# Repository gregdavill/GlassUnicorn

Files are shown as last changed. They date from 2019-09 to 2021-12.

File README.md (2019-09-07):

# Glass Unicorn

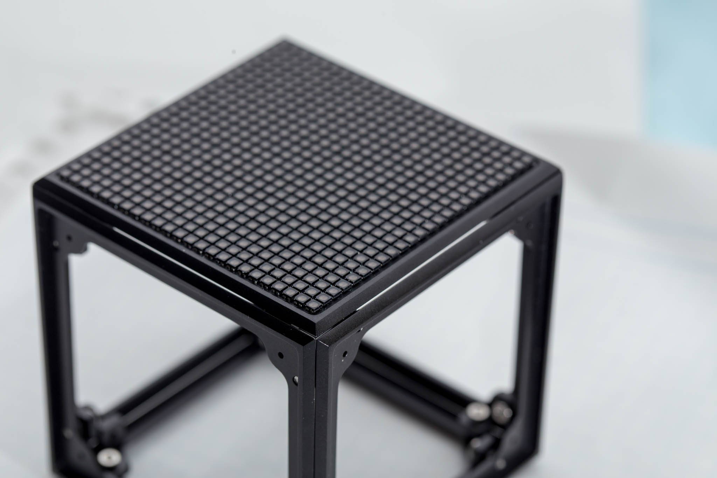
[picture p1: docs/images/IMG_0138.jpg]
LED Cube Top

## Colection of various dense LED matrix projects

	Project status: Work in progress

## Panel_r0.1
 * 24x24 RGB 2020 LEDs
 * Matrix construction with 4bit wide serial input.
 * Optimised for low cost: ~$15 BOM cost

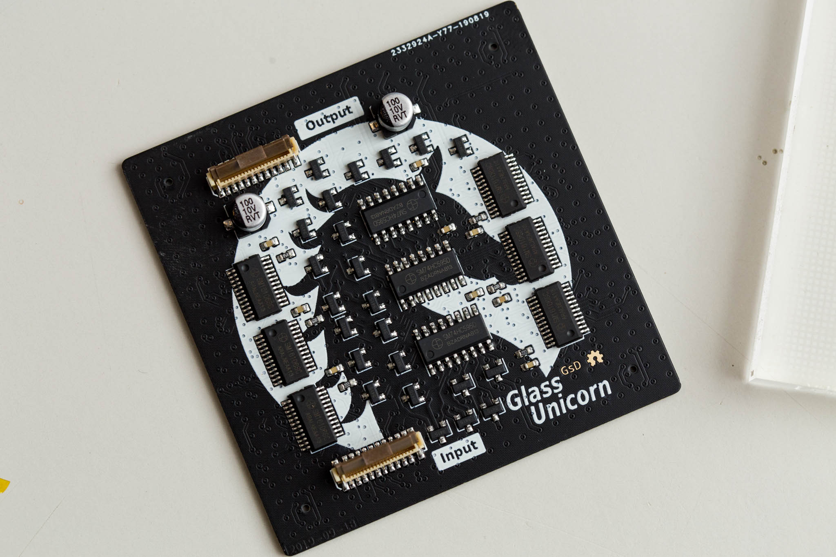
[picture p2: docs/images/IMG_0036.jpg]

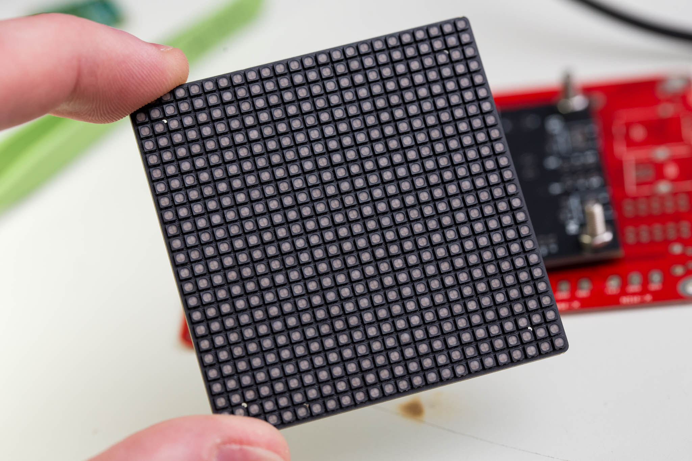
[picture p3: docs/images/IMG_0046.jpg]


## Cube_r0.1
 * Aluminium frame to fit the panels in a cube
 * ~64mm square

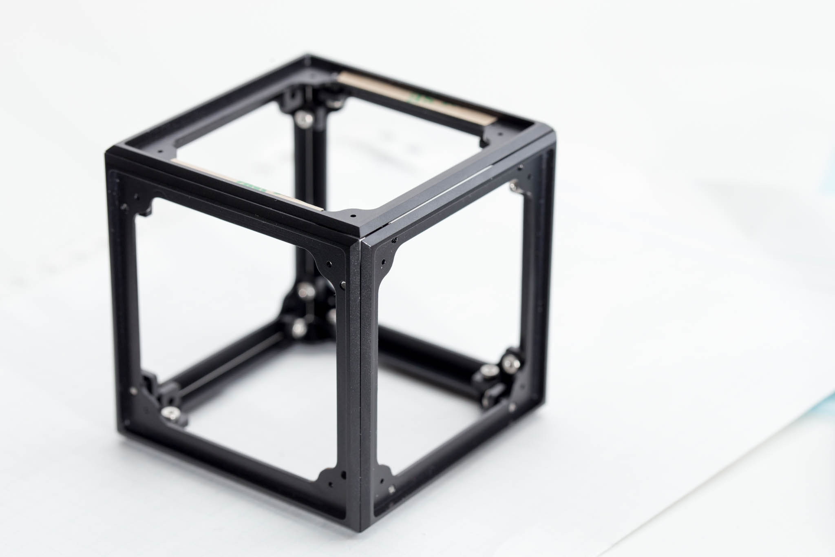
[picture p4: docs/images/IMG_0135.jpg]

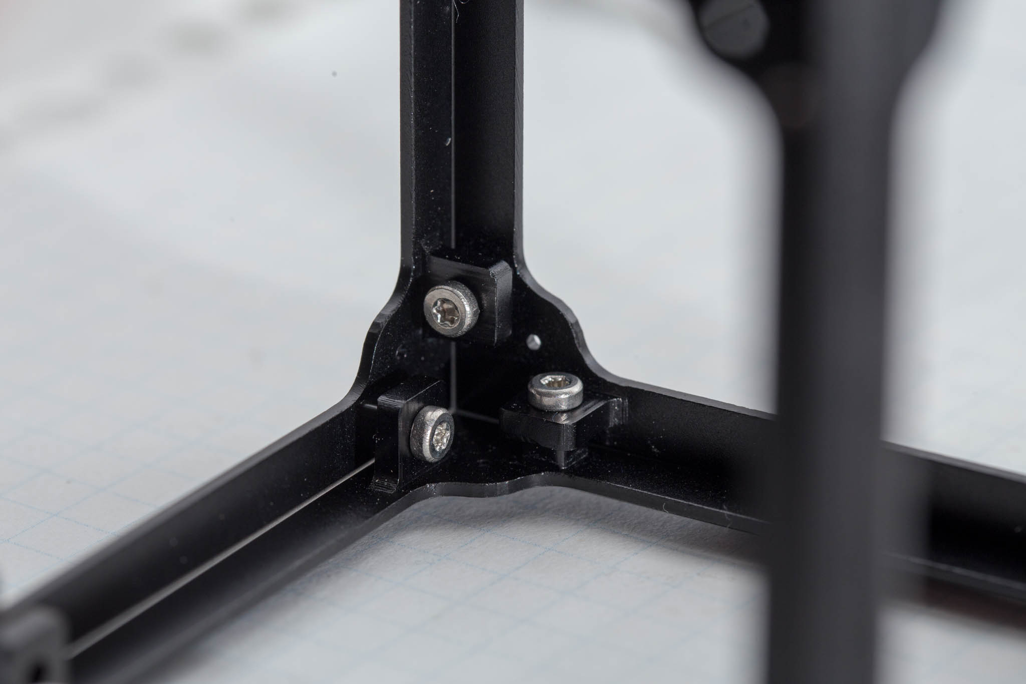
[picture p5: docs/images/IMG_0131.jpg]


## Controller_r0.1

    TBD

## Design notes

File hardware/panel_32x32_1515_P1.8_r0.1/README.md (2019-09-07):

# Panel_32x32_1515_P1.8

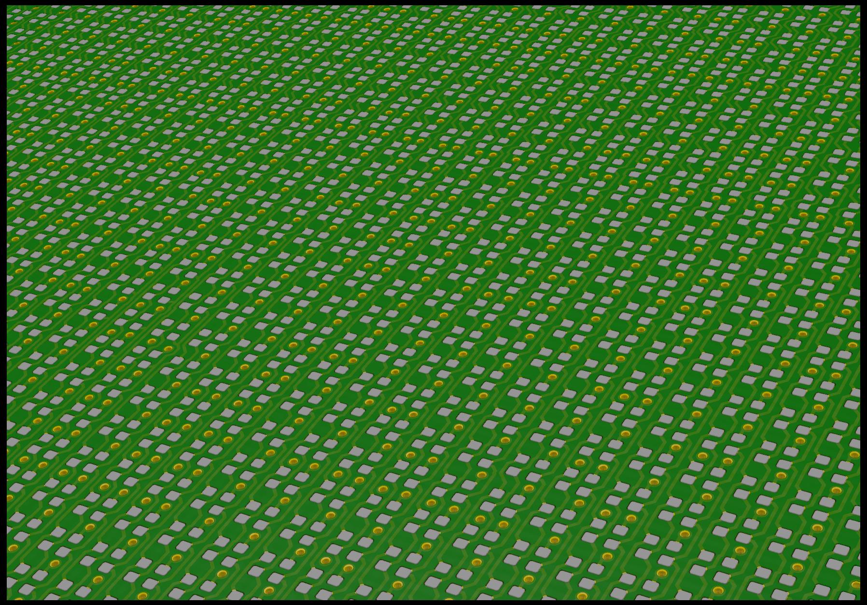
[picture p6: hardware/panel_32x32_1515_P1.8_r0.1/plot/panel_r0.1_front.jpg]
LED Cube Top

## Custom RGB LED panel

	Project status: Boards ordered

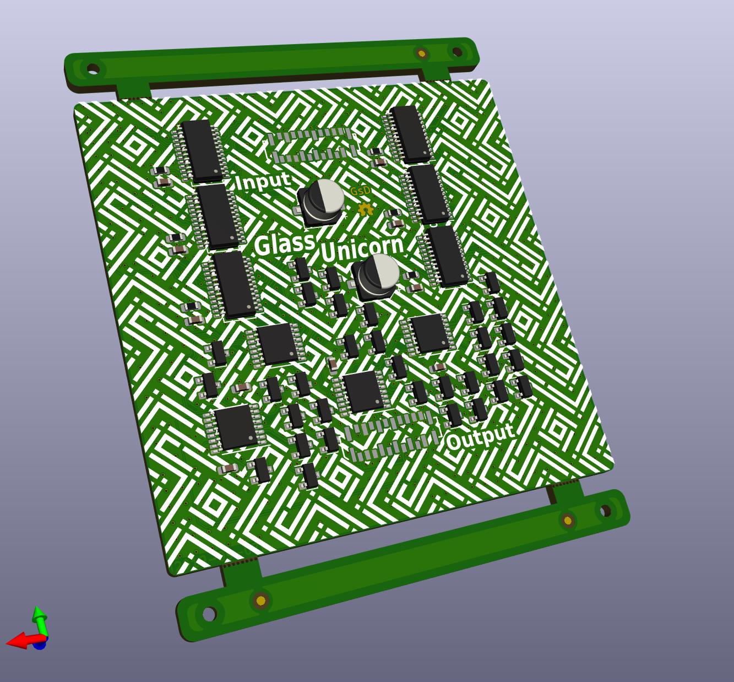
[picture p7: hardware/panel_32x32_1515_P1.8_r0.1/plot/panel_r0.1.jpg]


## Features
 * 32x32 RGB 1515 LEDs
 * Approximatey 1.8mm pixel pitch
 * Matrix construction with 4bit wide serial input.
 * BCM required for colour depth

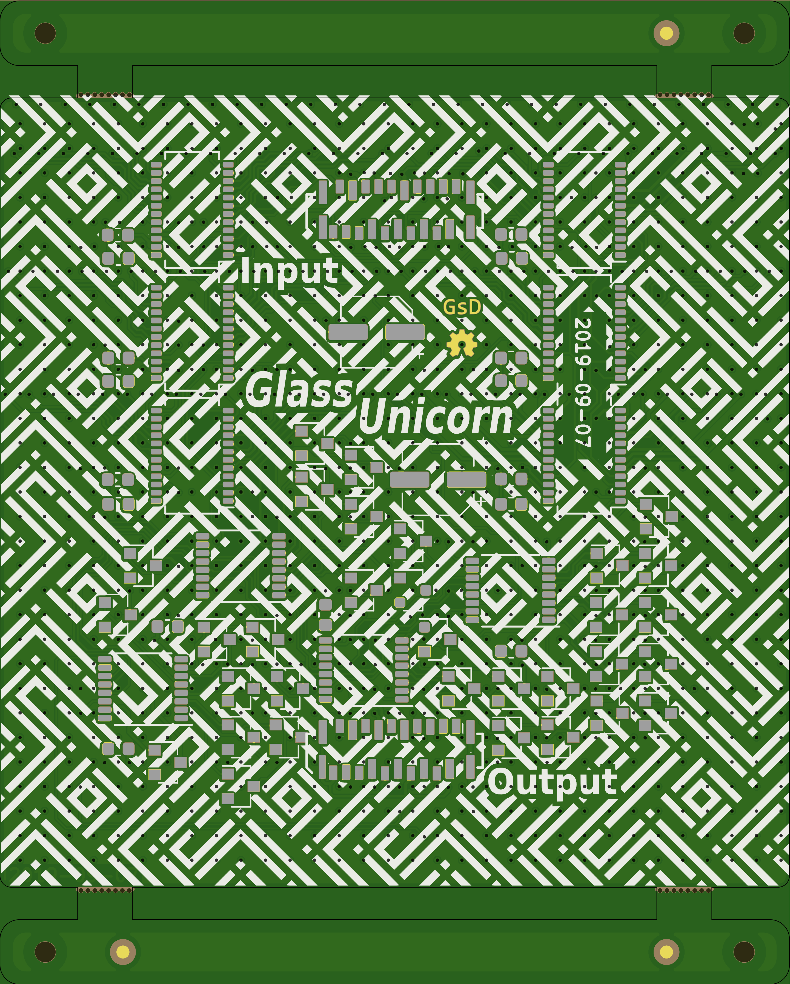
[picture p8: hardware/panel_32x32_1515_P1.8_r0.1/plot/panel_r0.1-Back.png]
"Bottom Photo" Bottom

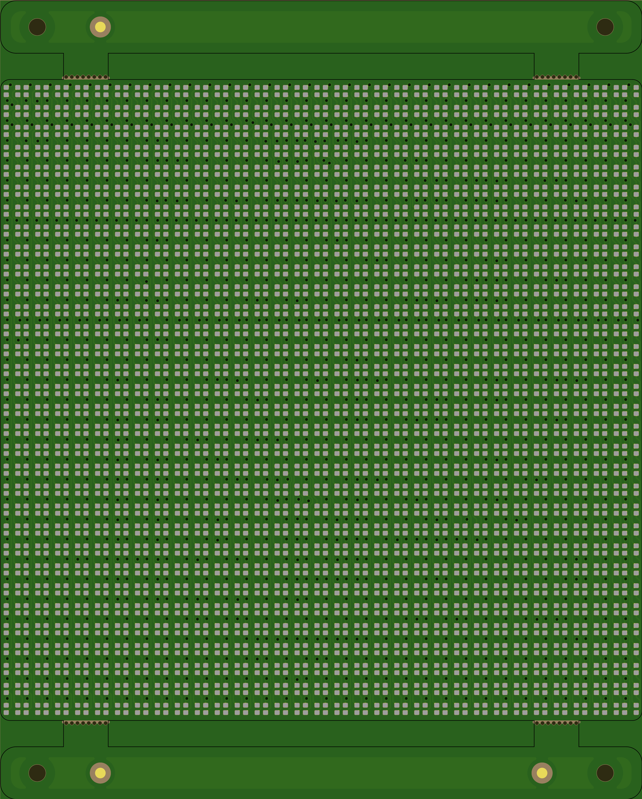
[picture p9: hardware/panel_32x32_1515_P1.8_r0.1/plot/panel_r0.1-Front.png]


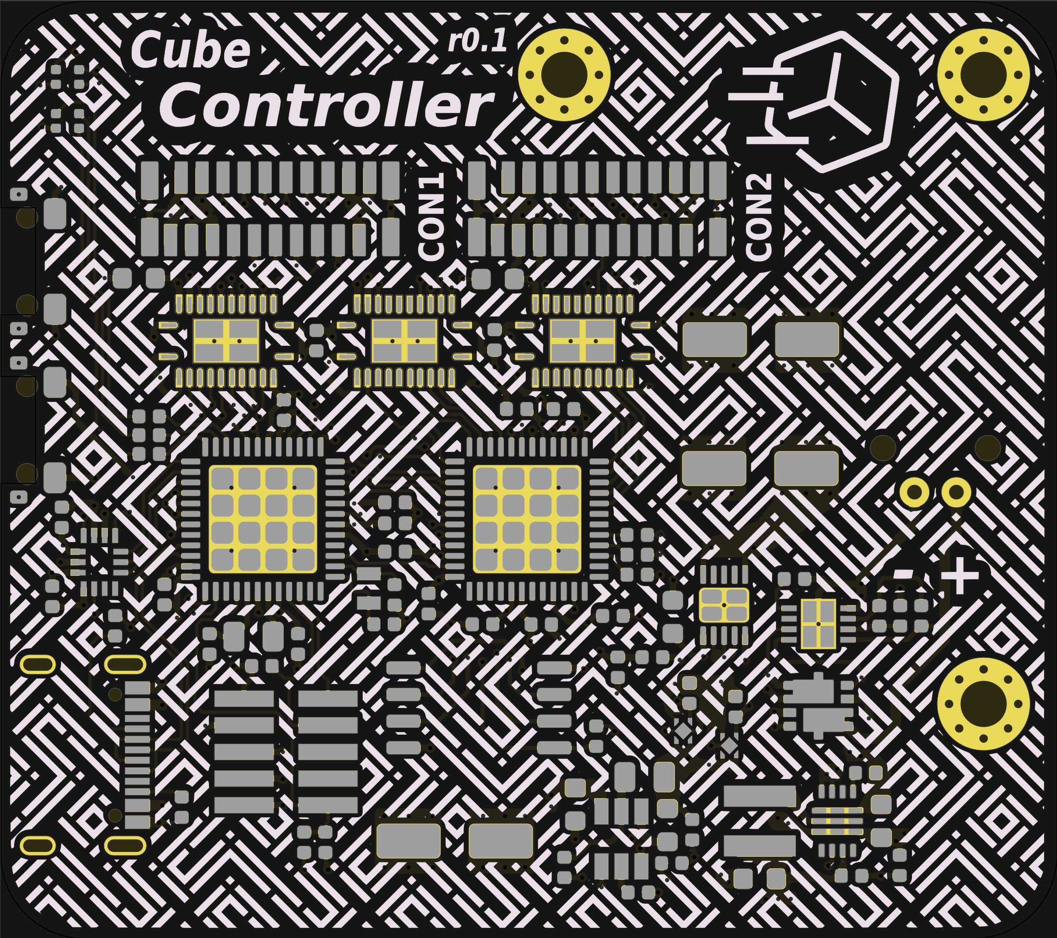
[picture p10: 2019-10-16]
hardware/cube-controller/plot/cube-controller-r0.1-Front.png

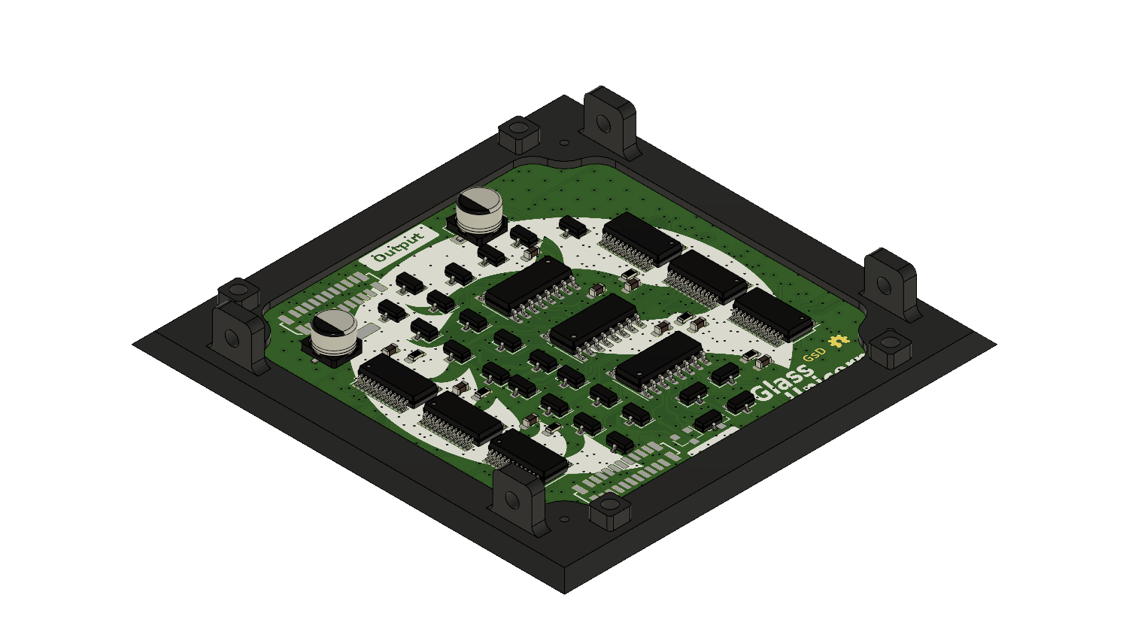
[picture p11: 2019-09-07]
docs/images/GlassUnicorn_Cube_r0.1.png

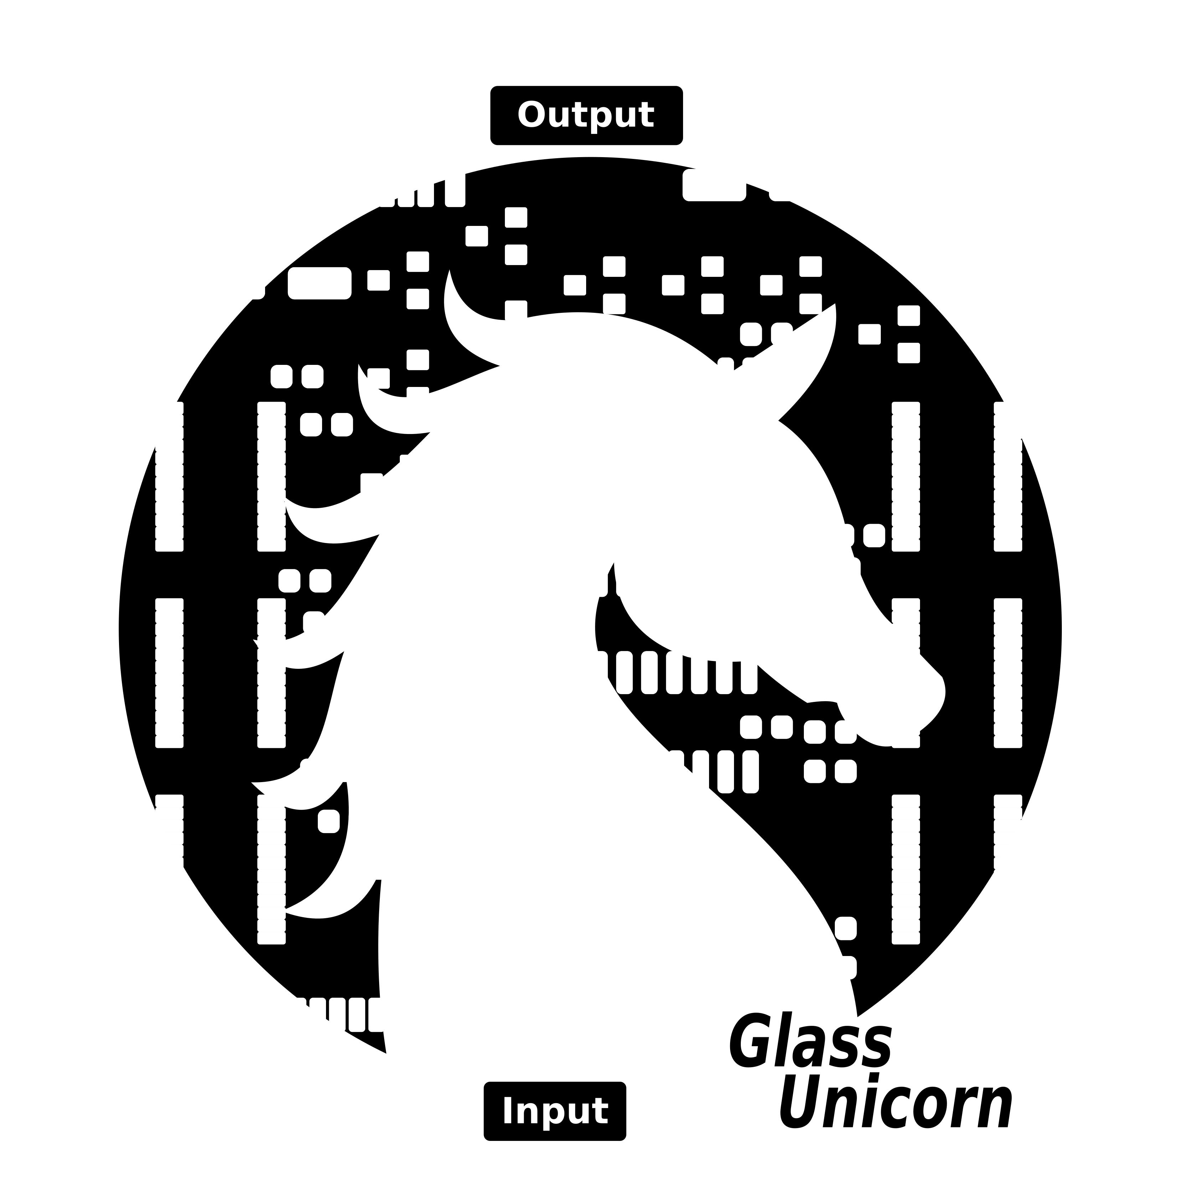
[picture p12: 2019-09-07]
ref/art.png

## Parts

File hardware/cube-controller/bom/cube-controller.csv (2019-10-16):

Source: | /home/greg/projects/GlassUnicorn/hardware/cube-controller/cube-controller.py
Date: | 10/16/2019 11:00 PM
Tool: | SKiDL (0.0.27)
Generator: | /usr/share/kicad/plugins/bom_csv_grouped_by_value.py
Component Count: | 83
Individual Components:
Item | Qty | Reference(s) | Value | LibPart | Footprint | Datasheet | F0 | F1 | F2 | F3 | Manf | PN | datasheet | description | keywords
 |  | C1 | 10uF | C | Capacitor_SMD:C_0603_1608Metric |  | C | C |  |  | Murata Electronics | GRM188R61C106MAALD | ~ | Unpolarized capacitor | cap capacitor
 |  | C2 | 10uF | C | Capacitor_SMD:C_0603_1608Metric |  | C | C |  |  | Murata Electronics | GRM188R61C106MAALD | ~ | Unpolarized capacitor | cap capacitor
 |  | C3 | 100nF | C | Capacitor_SMD:C_0402_1005Metric |  | C | C |  |  | Samsung Electro-Mechanics | CL05B104KP5NNNC | ~ | Unpolarized capacitor | cap capacitor
 |  | C4 | 10uF | C | Capacitor_SMD:C_0603_1608Metric |  | C | C |  |  | Murata Electronics | GRM188R61C106MAALD | ~ | Unpolarized capacitor | cap capacitor
 |  | C5 | 10uF | C | Capacitor_SMD:C_0603_1608Metric |  | C | C |  |  | Murata Electronics | GRM188R61C106MAALD | ~ | Unpolarized capacitor | cap capacitor
 |  | C6 | 1uF | C | Capacitor_SMD:C_0402_1005Metric |  | C | C |  |  | Samsung Electro-Mechanics | CL05A105MQ5NNNC | ~ | Unpolarized capacitor | cap capacitor
 |  | C7 | 1uF | C | Capacitor_SMD:C_0402_1005Metric |  | C | C |  |  | Samsung Electro-Mechanics | CL05A105MQ5NNNC | ~ | Unpolarized capacitor | cap capacitor
 |  | C8 | 1uF | C | Capacitor_SMD:C_0402_1005Metric |  | C | C |  |  | Samsung Electro-Mechanics | CL05A105MQ5NNNC | ~ | Unpolarized capacitor | cap capacitor
 |  | C9 | CP1 | CP1 | Capacitor_SMD:CP_Elec_5x3.9 |  | C | CP1 |  |  | Nichicon | UWX1C101MCL1GB | ~ | Polarized capacitor, US symbol | cap capacitor
 |  | C10 | CP1 | CP1 | Capacitor_SMD:CP_Elec_5x3.9 |  | C | CP1 |  |  | Nichicon | UWX1C101MCL1GB | ~ | Polarized capacitor, US symbol | cap capacitor
 |  | C11 | CP1 | CP1 | Capacitor_SMD:CP_Elec_5x3.9 |  | C | CP1 |  |  | Nichicon | UWX1C101MCL1GB | ~ | Polarized capacitor, US symbol | cap capacitor
 |  | C12 | 100nF | C | Capacitor_SMD:C_0402_1005Metric |  | C | C |  |  | Samsung Electro-Mechanics | CL05B104KP5NNNC | ~ | Unpolarized capacitor | cap capacitor
 |  | C13 | 100nF | C | Capacitor_SMD:C_0402_1005Metric |  | C | C |  |  | Samsung Electro-Mechanics | CL05B104KP5NNNC | ~ | Unpolarized capacitor | cap capacitor
 |  | C14 | 100nF | C | Capacitor_SMD:C_0402_1005Metric |  | C | C |  |  | Samsung Electro-Mechanics | CL05B104KP5NNNC | ~ | Unpolarized capacitor | cap capacitor
 |  | C15 | 100nF | C | Capacitor_SMD:C_0402_1005Metric |  | C | C |  |  | Samsung Electro-Mechanics | CL05B104KP5NNNC | ~ | Unpolarized capacitor | cap capacitor
 |  | C16 | 1uF | C | Capacitor_SMD:C_0402_1005Metric |  | C | C |  |  | Samsung Electro-Mechanics | CL05A105MQ5NNNC | ~ | Unpolarized capacitor | cap capacitor
 |  | C17 | 22pF | C | Capacitor_SMD:C_0402_1005Metric |  | C | C |  |  | Yageo | CC0402JRNPO9BN220 | ~ | Unpolarized capacitor | cap capacitor
 |  | C18 | 22pF | C | Capacitor_SMD:C_0402_1005Metric |  | C | C |  |  | Yageo | CC0402JRNPO9BN220 | ~ | Unpolarized capacitor | cap capacitor
 |  | C19 | 100nF | C | Capacitor_SMD:C_0402_1005Metric |  | C | C |  |  | Samsung Electro-Mechanics | CL05B104KP5NNNC | ~ | Unpolarized capacitor | cap capacitor
 |  | C20 | 100nF | C | Capacitor_SMD:C_0402_1005Metric |  | C | C |  |  | Samsung Electro-Mechanics | CL05B104KP5NNNC | ~ | Unpolarized capacitor | cap capacitor
 |  | C21 | 100nF | C | Capacitor_SMD:C_0402_1005Metric |  | C | C |  |  | Samsung Electro-Mechanics | CL05B104KP5NNNC | ~ | Unpolarized capacitor | cap capacitor
 |  | C22 | 100nF | C | Capacitor_SMD:C_0402_1005Metric |  | C | C |  |  | Samsung Electro-Mechanics | CL05B104KP5NNNC | ~ | Unpolarized capacitor | cap capacitor
 |  | C23 | 100nF | C | Capacitor_SMD:C_0402_1005Metric |  | C | C |  |  | Samsung Electro-Mechanics | CL05B104KP5NNNC | ~ | Unpolarized capacitor | cap capacitor
 |  | C24 | 100nF | C | Capacitor_SMD:C_0402_1005Metric |  | C | C |  |  | Samsung Electro-Mechanics | CL05B104KP5NNNC | ~ | Unpolarized capacitor | cap capacitor
 |  | C25 | 100nF | C | Capacitor_SMD:C_0402_1005Metric |  | C | C |  |  | Samsung Electro-Mechanics | CL05B104KP5NNNC | ~ | Unpolarized capacitor | cap capacitor
 |  | C26 | 10uF | C | Capacitor_SMD:C_0603_1608Metric |  | C | C |  |  | Murata Electronics | GRM188R61C106MAALD | ~ | Unpolarized capacitor | cap capacitor
 |  | C27 | 100nF | C | Capacitor_SMD:C_0402_1005Metric |  | C | C |  |  | Samsung Electro-Mechanics | CL05B104KP5NNNC | ~ | Unpolarized capacitor | cap capacitor
 |  | C28 | 10uF | C | Capacitor_SMD:C_0603_1608Metric |  | C | C |  |  | Murata Electronics | GRM188R61C106MAALD | ~ | Unpolarized capacitor | cap capacitor
 |  | C29 | 100nF | C | Capacitor_SMD:C_0402_1005Metric |  | C | C |  |  | Samsung Electro-Mechanics | CL05B104KP5NNNC | ~ | Unpolarized capacitor | cap capacitor
 |  | C30 | 100nF | C | Capacitor_SMD:C_0402_1005Metric |  | C | C |  |  | Samsung Electro-Mechanics | CL05B104KP5NNNC | ~ | Unpolarized capacitor | cap capacitor
 |  | C31 | 100nF | C | Capacitor_SMD:C_0402_1005Metric |  | C | C |  |  | Samsung Electro-Mechanics | CL05B104KP5NNNC | ~ | Unpolarized capacitor | cap capacitor
 |  | C32 | 100nF | C | Capacitor_SMD:C_0402_1005Metric |  | C | C |  |  | Samsung Electro-Mechanics | CL05B104KP5NNNC | ~ | Unpolarized capacitor | cap capacitor
 |  | C33 | 10uF | C | Capacitor_SMD:C_0603_1608Metric |  | C | C |  |  | Murata Electronics | GRM188R61C106MAALD | ~ | Unpolarized capacitor | cap capacitor
 |  | D1 | LED_ARGB | LED_ARGB | gkl_led:led_rbag_1515 |  | D | LED_ARGB |  |  | Meihua | MHPA1515RGBDT | ~ | RGB LED, anode/red/green/blue | LED RGB diode
 |  | D2 | LED_ARGB | LED_ARGB | gkl_led:led_rbag_1515 |  | D | LED_ARGB |  |  | Meihua | MHPA1515RGBDT | ~ | RGB LED, anode/red/green/blue | LED RGB diode
 |  | FB1 | Ferrite_Bead_Small | Ferrite_Bead_Small | Inductor_SMD:L_0402_1005Metric |  | FB | Ferrite_Bead_Small |  |  | Taiyo Yuden | BK1005HS102-T | ~ | Ferrite bead, small symbol | L ferrite bead inductor filter
 |  | J1 | Conn_01x02 | Conn_01x02 | gkl_conn:SB02B-PASK-2 |  | J | Conn_01x02 |  |  | JST Sales America Inc. | S02B-PASK-2(LF)(SN) | ~ | Generic connector, single row, 01x02, script generated (kicad-library-utils/schlib/autogen/connector/) | connector
 |  | J2 | Conn_01x20_Shielded | Conn_01x20_Shielded | gkl_conn:FH12-20S-0.5SVA(54) |  | J | Conn_01x20_Shielded |  |  | Hirose Electric Co Ltd | FH12-20S-0.5SVA(54) | ~ | Generic shielded connector, single row, 01x20, script generated (kicad-library-utils/schlib/autogen/connector/) | connector
 |  | J3 | Conn_01x20_Shielded | Conn_01x20_Shielded | gkl_conn:FH12-20S-0.5SVA(54) |  | J | Conn_01x20_Shielded |  |  | Hirose Electric Co Ltd | FH12-20S-0.5SVA(54) | ~ | Generic shielded connector, single row, 01x20, script generated (kicad-library-utils/schlib/autogen/connector/) | connector
 |  | J4 | Conn_02x05_Odd_Even | Conn_02x05_Odd_Even | gkl_conn:FTSH-105-XX-X-DV |  | J | Conn_02x05_Odd_Even |  |  | Samtec Inc. | FTSH-105-01-F-DV-K-TR | ~ | Generic connector, double row, 02x05, odd/even pin numbering scheme (row 1 odd numbers, row 2 even numbers), script generated (kicad-library-utils/schlib/autogen/connector/) | connector
 |  | J5 | USB_C_Receptacle_USB2.0 | USB_C_Receptacle_USB2.0 | Connector_USB:USB_C_Receptacle_Palconn_UTC16-G |  | J | USB_C_Receptacle_USB2.0 |  |  | Hirose Electric Co Ltd | CX90M-16P | https://www.usb.org/sites/default/files/documents/usb_type-c.zip | USB 2.0-only Type-C Receptacle connector | usb universal serial bus type-C USB2.0
 |  | L1 | 1uH | L | Inductor_SMD:L_Coilcraft_XxL4020 |  | L | L |  |  | Wurth Electronics Inc. | 78438357010 | ~ | Inductor | inductor choke coil reactor magnetic
 |  | L2 | 2.2uH | L | Inductor_SMD:L_0805_2012Metric |  | L | L |  |  | Murata Electronics | LQM21FN2R2N00D | ~ | Inductor | inductor choke coil reactor magnetic
 |  | L3 | 10uH | L | Inductor_SMD:L_0805_2012Metric |  | L | L |  |  | Murata Electronics | LQM21FN100M70L | ~ | Inductor | inductor choke coil reactor magnetic
 |  | R1 | 510k | R | Resistor_SMD:R_0402_1005Metric |  | R | R |  |  | Yageo | RC0402FR-07510KL | ~ | Resistor | R res resistor
 |  | R2 | 25.3k | R | Resistor_SMD:R_0402_1005Metric |  | R | R |  |  | Yageo | RC0402FR-0725K3L | ~ | Resistor | R res resistor
 |  | R3 | 34.8k | R | Resistor_SMD:R_0402_1005Metric |  | R | R |  |  | Yageo | RC0402FR-0734K8L | ~ | Resistor | R res resistor
 |  | R4 | 750k | R | Resistor_SMD:R_0402_1005Metric |  | R | R |  |  | Yageo | RC0402FR-07750KL | ~ | Resistor | R res resistor
 |  | R5 | 100k | R | Resistor_SMD:R_0402_1005Metric |  | R | R |  |  | Yageo | RC0402FR-07100KL | ~ | Resistor | R res resistor
 |  | R6 | 510k | R | Resistor_SMD:R_0402_1005Metric |  | R | R |  |  | Yageo | RC0402FR-07510KL | ~ | Resistor | R res resistor
 |  | R7 | 93.1k | R | Resistor_SMD:R_0402_1005Metric |  | R | R |  |  | Yageo | RC0402FR-0793K1L | ~ | Resistor | R res resistor
 |  | R8 | 100k | R | Resistor_SMD:R_0402_1005Metric |  | R | R |  |  | Yageo | RC0402FR-07100KL | ~ | Resistor | R res resistor
 |  | R9 | 33.2k | R | Resistor_SMD:R_0402_1005Metric |  | R | R |  |  | Yageo | RC0402FR-0733K2L | ~ | Resistor | R res resistor
 |  | R10 | 10k | R | Resistor_SMD:R_0402_1005Metric |  | R | R |  |  | Yageo | RC0402FR-0710KL | ~ | Resistor | R res resistor
 |  | R11 | 470R | R | Resistor_SMD:R_0402_1005Metric |  | R | R |  |  | Yageo | RC0402FR-07470RL | ~ | Resistor | R res resistor
 |  | R12 | 470R | R | Resistor_SMD:R_0402_1005Metric |  | R | R |  |  | Yageo | RC0402FR-07470RL | ~ | Resistor | R res resistor
 |  | R13 | 470R | R | Resistor_SMD:R_0402_1005Metric |  | R | R |  |  | Yageo | RC0402FR-07470RL | ~ | Resistor | R res resistor
 |  | R14 | 470R | R | Resistor_SMD:R_0402_1005Metric |  | R | R |  |  | Yageo | RC0402FR-07470RL | ~ | Resistor | R res resistor
 |  | R15 | 470R | R | Resistor_SMD:R_0402_1005Metric |  | R | R |  |  | Yageo | RC0402FR-07470RL | ~ | Resistor | R res resistor
 |  | R16 | 470R | R | Resistor_SMD:R_0402_1005Metric |  | R | R |  |  | Yageo | RC0402FR-07470RL | ~ | Resistor | R res resistor
 |  | R17 | 10k | R | Resistor_SMD:R_0402_1005Metric |  | R | R |  |  | Yageo | RC0402FR-0710KL | ~ | Resistor | R res resistor
 |  | R18 | 1k | R | Resistor_SMD:R_0402_1005Metric |  | R | R |  |  | Yageo | RC0402FR-071KL | ~ | Resistor | R res resistor
 |  | R19 | 10k | R | Resistor_SMD:R_0402_1005Metric |  | R | R |  |  | Yageo | RC0402FR-0710KL | ~ | Resistor | R res resistor
 |  | R20 | 10k | R | Resistor_SMD:R_0402_1005Metric |  | R | R |  |  | Yageo | RC0402FR-0710KL | ~ | Resistor | R res resistor
 |  | R21 | 5.1k | 5.1k | Resistor_SMD:R_0402_1005Metric |  | R | R |  |  | Yageo | RC0402FR-075K1L | ~ | Resistor | R res resistor
 |  | R22 | 5.1k | 5.1k | Resistor_SMD:R_0402_1005Metric |  | R | R |  |  | Yageo | RC0402FR-075K1L | ~ | Resistor | R res resistor
 |  | SW1 | SW_Push | SW_Push | gkl_misc:EVQP4 |  | SW | SW_Push |  |  | Panasonic Electronic Components | EVQ-P42B3M | ~ | Push button switch, generic, two pins | switch normally-open pushbutton push-button
 |  | SW2 | SW_Push | SW_Push | gkl_misc:EVQP4 |  | SW | SW_Push |  |  | Panasonic Electronic Components | EVQ-P42B3M | ~ | Push button switch, generic, two pins | switch normally-open pushbutton push-button
 |  | U1 | LTC4367 | LTC4367 | Package_DFN_QFN:DFN-8-1EP_3x3mm_P0.5mm_EP1.66x2.38mm |  | U | LTC4367 |  |  | Linear Technology/Analog Devices | LTC4367IDD#PBF
 |  | U2 | AON7804 | AON7804 | gkl_housings_dfn:DFN3X3_8L_EP2_P |  | U | AON7804 |  |  | Alpha / Omega Semiconductor Inc. | AON7804
 |  | U3 | TPS62135 | TPS62135 | gkl_misc:VQFN-11_3x2mm_P0.5mm |  | U | TPS62135 |  |  | Texas Instruments | TPS621351RGXR
 |  | U4 | TPS561201 | TPS561201 | Package_TO_SOT_SMD:TSOT-23-6 |  | U | TPS561201 |  |  | Texas Instruments | TPS561201DDCT
 |  | U5 | NP115-2.5 | NP115-2.5 | gkl_housings_son:X2SON_4_1.0x1.0mm |  | U | NCP167 |  | http://www.onsemi.com/pub/Collateral/NCP167-D.PDF | ON Semiconductor | NCP115CMX250TCG
 |  | U6 | NP115-1.2 | NP115-1.2 | gkl_housings_son:X2SON_4_1.0x1.0mm |  | U | NCP167 |  | http://www.onsemi.com/pub/Collateral/NCP167-D.PDF | ON Semiconductor | NCP115AMX120TCG
 |  | U7 | ATSAMD51G19A | ATSAMD51G19A | Package_DFN_QFN:QFN-48-1EP_7x7mm_P0.5mm_EP5.15x5.15mm |  | U | ATSAMD51G19A |  |  | Microchip Technology | ATSAMD51G19A-MF
 |  | U8 | ICE40UP5K-SG48ITR | ICE40UP5K-SG48ITR | Package_DFN_QFN:QFN-48-1EP_7x7mm_P0.5mm_EP5.15x5.15mm |  | U | ICE40UP5K-SG48ITR | Package_DFN_QFN:QFN-48-1EP_7x7mm_P0.5mm_EP5.6x5.6mm |  | Lattice Semiconductor Corporation | ICE40UP5K-SG48I | http://www.latticesemi.com/Products/FPGAandCPLD/iCE40Ultra | iCE40 UltraPlus FPGA, 5280 LUTs, 1.2V, 48-pin QFN | FPGA programmable logic
 |  | U9 | SN74AVC8T245PW | SN74AVC8T245PW | Package_DFN_QFN:Texas_RGY_R-PVQFN-N24_EP2.05x3.1mm |  | U | SN74AVC8T245PW | Package_SO:TSSOP-24_4.4x7.8mm_P0.65mm |  | Texas Instruments | SN74AVC8T245RHLR | https://www.ti.com/lit/ds/symlink/sn74avc8t245.pdf | 8-Bit Dual-Supply Bus Transceiver With Configurable Voltage Translation and 3-State Outputs, TSSOP-24 | Noninverting Bidirectional
 |  | U10 | SN74AVC8T245PW | SN74AVC8T245PW | Package_DFN_QFN:Texas_RGY_R-PVQFN-N24_EP2.05x3.1mm |  | U | SN74AVC8T245PW | Package_SO:TSSOP-24_4.4x7.8mm_P0.65mm |  | Texas Instruments | SN74AVC8T245RHLR | https://www.ti.com/lit/ds/symlink/sn74avc8t245.pdf | 8-Bit Dual-Supply Bus Transceiver With Configurable Voltage Translation and 3-State Outputs, TSSOP-24 | Noninverting Bidirectional
 |  | U11 | SN74AVC8T245PW | SN74AVC8T245PW | Package_DFN_QFN:Texas_RGY_R-PVQFN-N24_EP2.05x3.1mm |  | U | SN74AVC8T245PW | Package_SO:TSSOP-24_4.4x7.8mm_P0.65mm |  | Texas Instruments | SN74AVC8T245RHLR | https://www.ti.com/lit/ds/symlink/sn74avc8t245.pdf | 8-Bit Dual-Supply Bus Transceiver With Configurable Voltage Translation and 3-State Outputs, TSSOP-24 | Noninverting Bidirectional
 |  | U12 | BMX160 | BMX160 | Package_LGA:Bosch_LGA-14_3x2.5mm_P0.5mm |  | U | BMX160 |  |  | Bosch Sensortec | BMX160
 |  | U13 | AT25SF081 | AT25SF081 | Package_SO:SOIC-8_5.23x5.23mm_P1.27mm |  | U | AT25SF081 |  |  | Winbond Electronics | W25Q128JVSIM TR
 |  | U14 | LTC4413-2 | LTC4413-2 | Package_DFN_QFN:DFN-10-1EP_3x3mm_P0.5mm_EP1.65x2.38mm |  | U | LTC4413-2 |  |  | Linear Technology/Analog Devices | LTC4413EDD-1#PBF
 |  | Y1 | 32.768kHz | Crystal | Crystal:Crystal_SMD_2012-2Pin_2.0x1.2mm |  | Y | Crystal |  |  | ECS Inc. | ECS-.327-9-12R-C-TR | ~ | Two pin crystal | quartz ceramic resonator oscillator
Collated Components:
Item | Qty | Reference(s) | Value | LibPart | Footprint | Datasheet | F0 | F1 | F2 | F3 | Manf | PN | datasheet | description | keywords
1 | 7 | C1, C2, C4, C5, C26, C28, C33 | 10uF | C | Capacitor_SMD:C_0603_1608Metric | C | C |  |  | Murata Electronics | GRM188R61C106MAALD | ~ | Unpolarized capacitor | cap capacitor
2 | 17 | C3, C12, C13, C14, C15, C19, C20, C21, C22, C23, C24, C25, C27, C29, C30, C31, C32 | 100nF | C | Capacitor_SMD:C_0402_1005Metric | C | C |  |  | Samsung Electro-Mechanics | CL05B104KP5NNNC | ~ | Unpolarized capacitor | cap capacitor
3 | 4 | C6, C7, C8, C16 | 1uF | C | Capacitor_SMD:C_0402_1005Metric | C | C |  |  | Samsung Electro-Mechanics | CL05A105MQ5NNNC | ~ | Unpolarized capacitor | cap capacitor
4 | 3 | C9, C10, C11 | CP1 | CP1 | Capacitor_SMD:CP_Elec_5x3.9 | C | CP1 |  |  | Nichicon | UWX1C101MCL1GB | ~ | Polarized capacitor, US symbol | cap capacitor
5 | 2 | C17, C18 | 22pF | C | Capacitor_SMD:C_0402_1005Metric | C | C |  |  | Yageo | CC0402JRNPO9BN220 | ~ | Unpolarized capacitor | cap capacitor
6 | 2 | D1, D2 | LED_ARGB | LED_ARGB | gkl_led:led_rbag_1515 | D | LED_ARGB |  |  | Meihua | MHPA1515RGBDT | ~ | RGB LED, anode/red/green/blue | LED RGB diode
7 | 1 | FB1 | Ferrite_Bead_Small | Ferrite_Bead_Small | Inductor_SMD:L_0402_1005Metric | FB | Ferrite_Bead_Small |  |  | Taiyo Yuden | BK1005HS102-T | ~ | Ferrite bead, small symbol | L ferrite bead inductor filter
8 | 1 | J1 | Conn_01x02 | Conn_01x02 | gkl_conn:SB02B-PASK-2 | J | Conn_01x02 |  |  | JST Sales America Inc. | S02B-PASK-2(LF)(SN) | ~ | Generic connector, single row, 01x02, script generated (kicad-library-utils/schlib/autogen/connector/) | connector
9 | 2 | J2, J3 | Conn_01x20_Shielded | Conn_01x20_Shielded | gkl_conn:FH12-20S-0.5SVA(54) | J | Conn_01x20_Shielded |  |  | Hirose Electric Co Ltd | FH12-20S-0.5SVA(54) | ~ | Generic shielded connector, single row, 01x20, script generated (kicad-library-utils/schlib/autogen/connector/) | connector
10 | 1 | J4 | Conn_02x05_Odd_Even | Conn_02x05_Odd_Even | gkl_conn:FTSH-105-XX-X-DV | J | Conn_02x05_Odd_Even |  |  | Samtec Inc. | FTSH-105-01-F-DV-K-TR | ~ | Generic connector, double row, 02x05, odd/even pin numbering scheme (row 1 odd numbers, row 2 even numbers), script generated (kicad-library-utils/schlib/autogen/connector/) | connector
11 | 1 | J5 | USB_C_Receptacle_USB2.0 | USB_C_Receptacle_USB2.0 | Connector_USB:USB_C_Receptacle_Palconn_UTC16-G | J | USB_C_Receptacle_USB2.0 |  |  | Hirose Electric Co Ltd | CX90M-16P | https://www.usb.org/sites/default/files/documents/usb_type-c.zip | USB 2.0-only Type-C Receptacle connector | usb universal serial bus type-C USB2.0
12 | 1 | L1 | 1uH | L | Inductor_SMD:L_Coilcraft_XxL4020 | L | L |  |  | Wurth Electronics Inc. | 78438357010 | ~ | Inductor | inductor choke coil reactor magnetic
13 | 1 | L2 | 2.2uH | L | Inductor_SMD:L_0805_2012Metric | L | L |  |  | Murata Electronics | LQM21FN2R2N00D | ~ | Inductor | inductor choke coil reactor magnetic
14 | 1 | L3 | 10uH | L | Inductor_SMD:L_0805_2012Metric | L | L |  |  | Murata Electronics | LQM21FN100M70L | ~ | Inductor | inductor choke coil reactor magnetic
15 | 2 | R1, R6 | 510k | R | Resistor_SMD:R_0402_1005Metric | R | R |  |  | Yageo | RC0402FR-07510KL | ~ | Resistor | R res resistor
16 | 1 | R2 | 25.3k | R | Resistor_SMD:R_0402_1005Metric | R | R |  |  | Yageo | RC0402FR-0725K3L | ~ | Resistor | R res resistor
17 | 1 | R3 | 34.8k | R | Resistor_SMD:R_0402_1005Metric | R | R |  |  | Yageo | RC0402FR-0734K8L | ~ | Resistor | R res resistor
18 | 1 | R4 | 750k | R | Resistor_SMD:R_0402_1005Metric | R | R |  |  | Yageo | RC0402FR-07750KL | ~ | Resistor | R res resistor
19 | 2 | R5, R8 | 100k | R | Resistor_SMD:R_0402_1005Metric | R | R |  |  | Yageo | RC0402FR-07100KL | ~ | Resistor | R res resistor
20 | 1 | R7 | 93.1k | R | Resistor_SMD:R_0402_1005Metric | R | R |  |  | Yageo | RC0402FR-0793K1L | ~ | Resistor | R res resistor
21 | 1 | R9 | 33.2k | R | Resistor_SMD:R_0402_1005Metric | R | R |  |  | Yageo | RC0402FR-0733K2L | ~ | Resistor | R res resistor
22 | 4 | R10, R17, R19, R20 | 10k | R | Resistor_SMD:R_0402_1005Metric | R | R |  |  | Yageo | RC0402FR-0710KL | ~ | Resistor | R res resistor
23 | 6 | R11, R12, R13, R14, R15, R16 | 470R | R | Resistor_SMD:R_0402_1005Metric | R | R |  |  | Yageo | RC0402FR-07470RL | ~ | Resistor | R res resistor
24 | 1 | R18 | 1k | R | Resistor_SMD:R_0402_1005Metric | R | R |  |  | Yageo | RC0402FR-071KL | ~ | Resistor | R res resistor
25 | 2 | R21, R22 | 5.1k | 5.1k | Resistor_SMD:R_0402_1005Metric | R | R |  |  | Yageo | RC0402FR-075K1L | ~ | Resistor | R res resistor
26 | 2 | SW1, SW2 | SW_Push | SW_Push | gkl_misc:EVQP4 | SW | SW_Push |  |  | Panasonic Electronic Components | EVQ-P42B3M | ~ | Push button switch, generic, two pins | switch normally-open pushbutton push-button
27 | 1 | U1 | LTC4367 | LTC4367 | Package_DFN_QFN:DFN-8-1EP_3x3mm_P0.5mm_EP1.66x2.38mm | U | LTC4367 |  |  | Linear Technology/Analog Devices | LTC4367IDD#PBF
28 | 1 | U2 | AON7804 | AON7804 | gkl_housings_dfn:DFN3X3_8L_EP2_P | U | AON7804 |  |  | Alpha / Omega Semiconductor Inc. | AON7804
29 | 1 | U3 | TPS62135 | TPS62135 | gkl_misc:VQFN-11_3x2mm_P0.5mm | U | TPS62135 |  |  | Texas Instruments | TPS621351RGXR
30 | 1 | U4 | TPS561201 | TPS561201 | Package_TO_SOT_SMD:TSOT-23-6 | U | TPS561201 |  |  | Texas Instruments | TPS561201DDCT
31 | 1 | U5 | NP115-2.5 | NP115-2.5 | gkl_housings_son:X2SON_4_1.0x1.0mm | U | NCP167 |  | http://www.onsemi.com/pub/Collateral/NCP167-D.PDF | ON Semiconductor | NCP115CMX250TCG
32 | 1 | U6 | NP115-1.2 | NP115-1.2 | gkl_housings_son:X2SON_4_1.0x1.0mm | U | NCP167 |  | http://www.onsemi.com/pub/Collateral/NCP167-D.PDF | ON Semiconductor | NCP115AMX120TCG
33 | 1 | U7 | ATSAMD51G19A | ATSAMD51G19A | Package_DFN_QFN:QFN-48-1EP_7x7mm_P0.5mm_EP5.15x5.15mm | U | ATSAMD51G19A |  |  | Microchip Technology | ATSAMD51G19A-MF
34 | 1 | U8 | ICE40UP5K-SG48ITR | ICE40UP5K-SG48ITR | Package_DFN_QFN:QFN-48-1EP_7x7mm_P0.5mm_EP5.15x5.15mm | U | ICE40UP5K-SG48ITR | Package_DFN_QFN:QFN-48-1EP_7x7mm_P0.5mm_EP5.6x5.6mm |  | Lattice Semiconductor Corporation | ICE40UP5K-SG48I | http://www.latticesemi.com/Products/FPGAandCPLD/iCE40Ultra | iCE40 UltraPlus FPGA, 5280 LUTs, 1.2V, 48-pin QFN | FPGA programmable logic
35 | 3 | U9, U10, U11 | SN74AVC8T245PW | SN74AVC8T245PW | Package_DFN_QFN:Texas_RGY_R-PVQFN-N24_EP2.05x3.1mm | U | SN74AVC8T245PW | Package_SO:TSSOP-24_4.4x7.8mm_P0.65mm |  | Texas Instruments | SN74AVC8T245RHLR | https://www.ti.com/lit/ds/symlink/sn74avc8t245.pdf | 8-Bit Dual-Supply Bus Transceiver With Configurable Voltage Translation and 3-State Outputs, TSSOP-24 | Noninverting Bidirectional
36 | 1 | U12 | BMX160 | BMX160 | Package_LGA:Bosch_LGA-14_3x2.5mm_P0.5mm | U | BMX160 |  |  | Bosch Sensortec | BMX160
37 | 1 | U13 | AT25SF081 | AT25SF081 | Package_SO:SOIC-8_5.23x5.23mm_P1.27mm | U | AT25SF081 |  |  | Winbond Electronics | W25Q128JVSIM TR
38 | 1 | U14 | LTC4413-2 | LTC4413-2 | Package_DFN_QFN:DFN-10-1EP_3x3mm_P0.5mm_EP1.65x2.38mm | U | LTC4413-2 |  |  | Linear Technology/Analog Devices | LTC4413EDD-1#PBF
39 | 1 | Y1 | 32.768kHz | Crystal | Crystal:Crystal_SMD_2012-2Pin_2.0x1.2mm | Y | Crystal |  |  | ECS Inc. | ECS-.327-9-12R-C-TR | ~ | Two pin crystal | quartz ceramic resonator oscillator

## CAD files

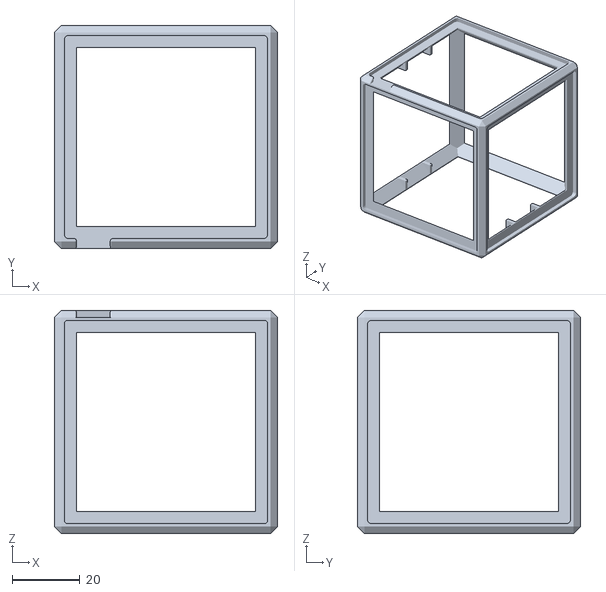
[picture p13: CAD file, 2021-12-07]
hardware/cube_r0.1/GlassUnicorn_Cube_Unibody_r0.2.stl
66.0 x 66.0 x 66.0

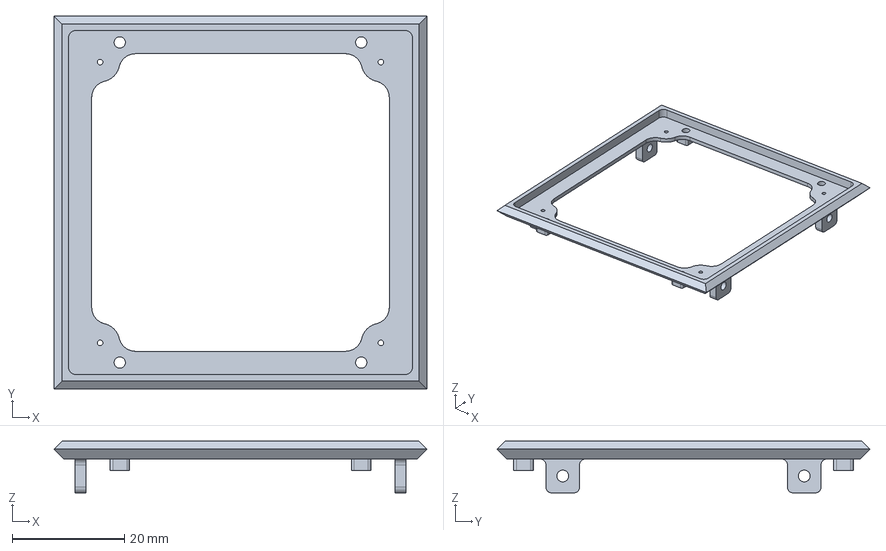
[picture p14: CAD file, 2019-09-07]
hardware/cube_r0.1/GlassUnicorn_Cube_r0.1.iges
66.4 x 66.4 x 9.20 mm

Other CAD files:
hardware/cube_r0.1/GlassUnicorn_Cube_Unibody_r0.2.prt
hardware/cube_r0.1/GlassUnicorn_Cube_r0.1.f3d

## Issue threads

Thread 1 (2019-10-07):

Suggestion: use high-side drivers with discharge to prevent ghosting

electroniceel, 2019-10-07:
You posted on twitter that you had some ghosting issues with your led panel.

One reason for ghosting can be charge that is built up by the high-side drivers and not drained before switching to the next row/column (whatever you use the highside for).

One solution is to use dedicated highside led drivers which have integrated transistors which actively pull low all outputs that are not enabled. For example this one:
https://lcsc.com/product-detail/LED-Drivers_TC7258E_C126213.html
(sorry, no english datasheet, but the Google translation looks fine to me)

I've read from other people that use resistors to add some minimum load on each highside-output. Don't know how well that works, probably more timing-dependant than the active drain.

gregdavill, 2019-10-13:
Interesting! I'll have to pick some up and experiment with them.

Looks like it wont be a drop in replacement. I also want to fully investigate exactly what conditions are causing the ghosting in my case.

arturo182, 2019-10-20:
Would it then also help to bodge pull down resistors on the mosfets on the existing design?

gregdavill, 2019-10-20:
If the issue turns out to be stray capacitance in columns that were activated without any rows active, we can probably try adding code to the gateware that essentially "skips" over any column fitting this description.

Adding hardware bodges will be good for debugging!

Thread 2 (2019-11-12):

Questions about FPGA source code

myxingchao, 2019-11-12:
After reading your project, I am very interested, I don't know how to get the FPGA source code.

greigs, 2019-11-13:
Some might be here.. I'm still waiting on my FPGA to try it.
https://github.com/gregdavill/ice40-playground/tree/master/cores/hub75

myxingchao, 2019-11-13:
Thank you for your reply, I am looking at the file is not found in the schematic of the control panel, I want to understand the principle to modify, maybe I can use ARM to try to develop

greigs, 2019-11-13:
This isn't schematic code. It is the FPGA code.
https://github.com/gregdavill/ice40-playground/tree/GlassUnicorn_24x24/projects/rgb_panel/rtl

gregdavill, 2019-11-28:
The panels are driven by an FPGA on the controller PCB. It's based on the rgb_panel code from here: https://github.com/smunaut/ice40-playground

This in turn is controlling the LEDs using Binary Coded Modulation. Here is a very detailed video on how this modulation scheme works. https://www.youtube.com/watch?v=Sq8SxVDO5wE

You should be able to develop similar code on an ARM if you wish.

gregdavill, 2019-11-28:
Here is another good video explaining how to drive panels similar to mine. Which would be a good starting point if you want to write your own. https://www.youtube.com/watch?v=6iHTbGsnI8Q

Closed 2019-12-01.

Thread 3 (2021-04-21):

P-Channel MOSFET Selection

mister-walter, 2021-04-21:
I'm trying to build one of your LED cubes, and was wondering if you could give any more information on the P-Channel MOSFETs that you used. I don't know a whole lot about component selection so I'm kind of flying by the seat of my pants here - I wasn't able to find any information about a P-Channel MOSFET with a designation 3412 (this is what appears in the BOM).

I'm mainly unsure about what max current capacity I should select for - the datasheet for the 2020 RGB LEDs that you linked on your blog indicates 20mA max forward current (I assume total between all color channels?), so my back-of-the-envelope calculation is 24 LEDs per row * 20mA = 0.5ish A. Therefore I should be looking for something with `Id > 1` and `Pd > 1.125W` (0.5A at 4.5V), right?

Thanks for posting this project!

gregdavill, 2021-04-21:
The parts are from LCSC, but it appears they no longer sell them, and they've removed the listing.

From the invoice I have when I bought them. They have the following description:
`3415, Shenzhen Fuman Elec, P-Channel 12V 4A 1.4V @ 250uA 55mΩ @ 3A,4.5V MOSFET `

mister-walter, 2021-04-22:
Thanks! I was able to find a similar MOSFET on LCSC.

Unrelated question - how did you select the resistor values for the TLC59025 clones? I'm planning to use an MBI5024 and I think I understand how to calculate the required resistor for a desired output current, but how did you determine the output currents for the 3 channels/what output current did you end up selecting for each?

gregdavill, 2021-04-22:
I used the values from an off the shelf 64x64 LED panel. But it hod different controller ICs. So my white balance isn't great.

I think my currents are all around the 2-5mA range. I opted to go a bit lower to get better dynamic range. and I didn't need to blind anyone.

I'd recommend building up a board, and maybe trying to fit a trim-pot for each channel, and then with actual content displayed on the panel adjust for the best looking image, then use those values for the rest of the panels.

Closed 2021-04-28.

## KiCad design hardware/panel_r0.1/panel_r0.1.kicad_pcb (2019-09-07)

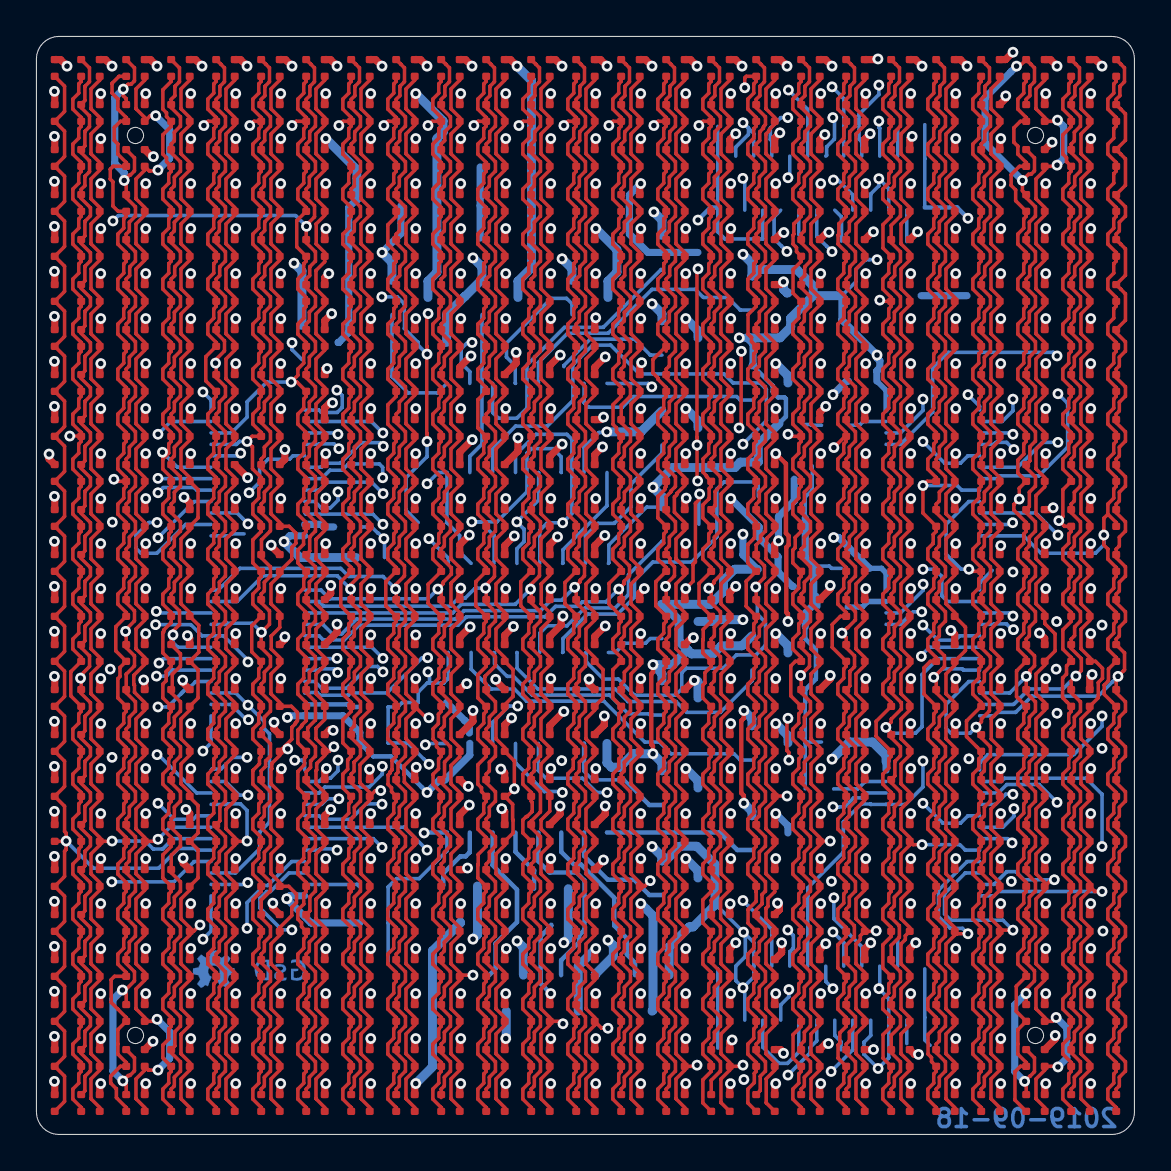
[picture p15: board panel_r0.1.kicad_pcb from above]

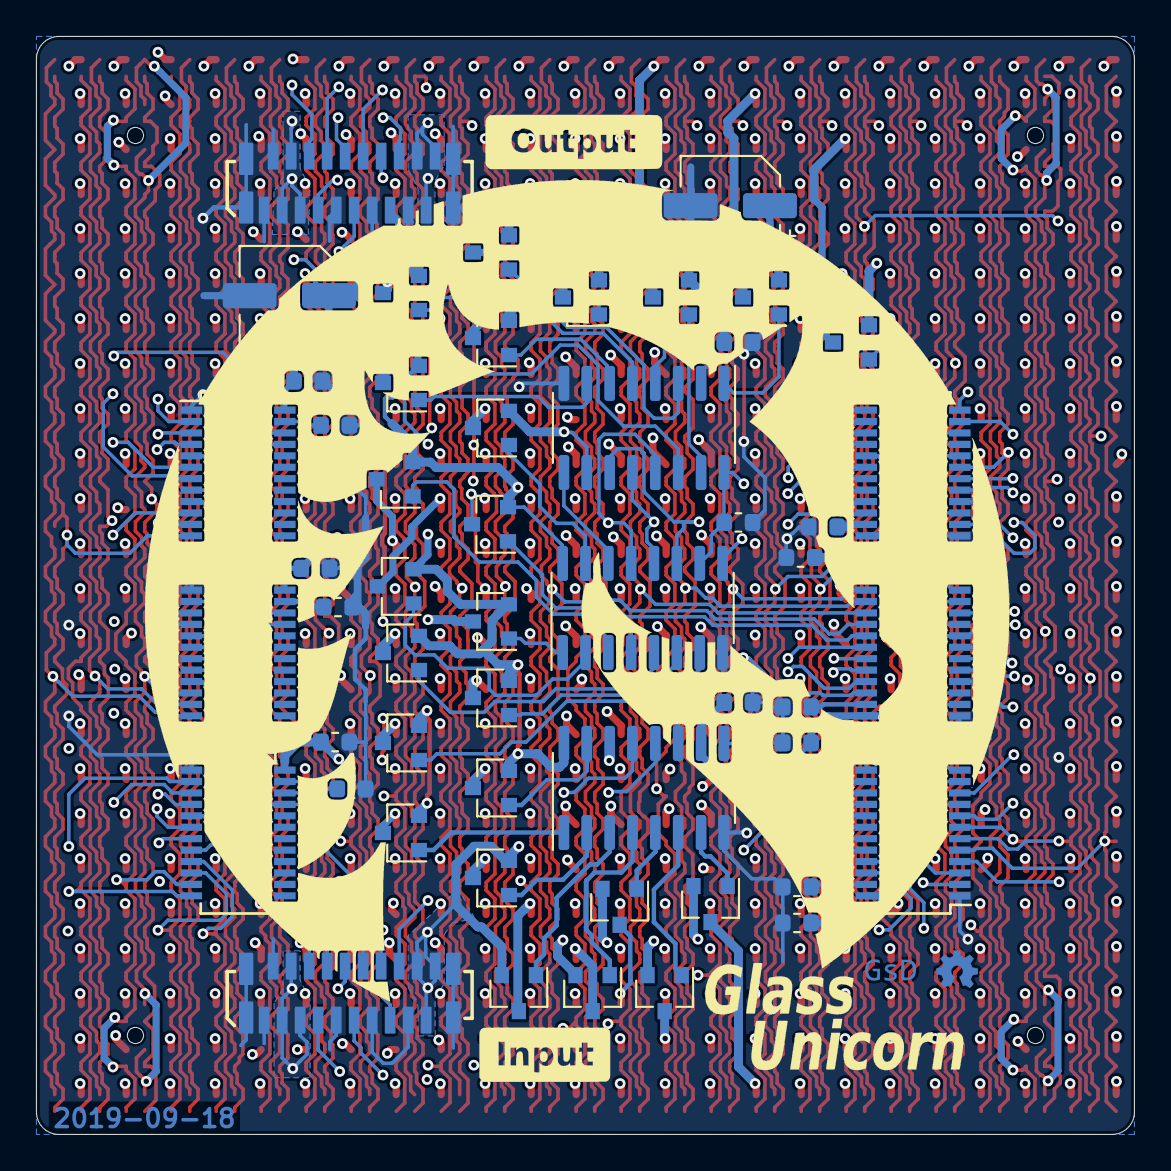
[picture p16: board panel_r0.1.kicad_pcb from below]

Board: 4 copper layers, 61.0 x 61.0 mm, 628 parts (52 on the bottom side), 146 nets.

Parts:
C1, C2, C3, C4, C5, C6, C7, C8, C9: 100nF; C_0603_1608Metric
C10, C11: 100uF; CP_Elec_5x3.9
D1, D2, D3, D4, D5, D6, D7, D8, D9, D10, D11, D12, D13, D14, D15, D16, D17, D18, D19, D20, D21, D22, D23, D24, D25, D26, D27, D28, D29, D30, D31, D32, D33, D34, D35, D36, D37, D38, D39, D40, D41, D42, D43, D44, D45, D46, D47, D48, D49, D50, D51, D52, D53, D54, D55, D56, D57, D58, D59, D60, D61, D62, D63, D64, D65, D66, D67, D68, D69, D70, D71, D72, D73, D74, D75, D76, D77, D78, D79, D80, D81, D82, D83, D84, D85, D86, D87, D88, D89, D90, D91, D92, D93, D94, D95, D96, D97, D98, D99, D100, D101, D102, D103, D104, D105, D106, D107, D108, D109, D110, D111, D112, D113, D114, D115, D116, D117, D118, D119, D120, D121, D122, D123, D124, D125, D126, D127, D128, D129, D130, D131, D132, D133, D134, D135, D136, D137, D138, D139, D140, D141, D142, D143, D144, D145, D146, D147, D148, D149, D150, D151, D152, D153, D154, D155, D156, D157, D158, D159, D160, D161, D162, D163, D164, D165, D166, D167, D168, D169, D170, D171, D172, D173, D174, D175, D176, D177, D178, D179, D180, D181, D182, D183, D184, D185, D186, D187, D188, D189, D190, D191, D192, D193, D194, D195, D196, D197, D198, D199, D200, D201, D202, D203, D204, D205, D206, D207, D208, D209, D210, D211, D212, D213, D214, D215, D216, D217, D218, D219, D220, D221, D222, D223, D224, D225, D226, D227, D228, D229, D230, D231, D232, D233, D234, D235, D236, D237, D238, D239, D240, D241, D242, D243, D244, D245, D246, D247, D248, D249, D250, D251, D252, D253, D254, D255, D256, D257, D258, D259, D260, D261, D262, D263, D264, D265, D266, D267, D268, D269, D270, D271, D272, D273, D274, D275, D276, D277, D278, D279, D280, D281, D282, D283, D284, D285, D286, D287, D288, D289, D290, D291, D292, D293, D294, D295, D296, D297, D298, D299, D300, D301, D302, D303, D304, D305, D306, D307, D308, D309, D310, D311, D312, D313, D314, D315, D316, D317, D318, D319, D320, D321, D322, D323, D324, D325, D326, D327, D328, D329, D330, D331, D332, D333, D334, D335, D336, D337, D338, D339, D340, D341, D342, D343, D344, D345, D346, D347, D348, D349, D350, D351, D352, D353, D354, D355, D356, D357, D358, D359, D360, D361, D362, D363, D364, D365, D366, D367, D368, D369, D370, D371, D372, D373, D374, D375, D376, D377, D378, D379, D380, D381, D382, D383, D384, D385, D386, D387, D388, D389, D390, D391, D392, D393, D394, D395, D396, D397, D398, D399, D400, D401, D402, D403, D404, D405, D406, D407, D408, D409, D410, D411, D412, D413, D414, D415, D416, D417, D418, D419, D420, D421, D422, D423, D424, D425, D426, D427, D428, D429, D430, D431, D432, D433, D434, D435, D436, D437, D438, D439, D440, D441, D442, D443, D444, D445, D446, D447, D448, D449, D450, D451, D452, D453, D454, D455, D456, D457, D458, D459, D460, D461, D462, D463, D464, D465, D466, D467, D468, D469, D470, D471, D472, D473, D474, D475, D476, D477, D478, D479, D480, D481, D482, D483, D484, D485, D486, D487, D488, D489, D490, D491, D492, D493, D494, D495, D496, D497, D498, D499, D500, D501, D502, D503, D504, D505, D506, D507, D508, D509, D510, D511, D512, D513, D514, D515, D516, D517, D518, D519, D520, D521, D522, D523, D524, D525, D526, D527, D528, D529, D530, D531, D532, D533, D534, D535, D536, D537, D538, D539, D540, D541, D542, D543, D544, D545, D546, D547, D548, D549, D550, D551, D552, D553, D554, D555, D556, D557, D558, D559, D560, D561, D562, D563, D564, D565, D566, D567, D568, D569, D570, D571, D572, D573, D574, D575, D576: LED_ARGB; led_rbag_2121_dense
J1, J2: Conn_01x20_Shielded; FH12-20S-0.5SVA(54)
Q1, Q2, Q3, Q4, Q5, Q6, Q7, Q8, Q9, Q10, Q11, Q12, Q13, Q14, Q15, Q16, Q17, Q18, Q19, Q20, Q21, Q22, Q23, Q24: 3412; SOT-23
R1, R2, R3, R4, R5, R6: R; R_0603_1608Metric
U1, U2, U3: 74HC595; SOIC-16_3.9x9.9mm_P1.27mm
U4, U5, U6, U7, U8, U9: TLC59025; SSOP-24_3.9x8.7mm_P0.635mm

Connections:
/ledArray/B: J1.8, U8.2
/ledArray/BLANK: J1.12, J2.12, U4.21, U5.21, U6.21, U7.21, U8.21, U9.21
/ledArray/Bout: J2.8, U9.22
/ledArray/G: J1.6, U4.2
/ledArray/Gout: J2.6, U5.22
/ledArray/LATCH: J1.11, J2.11, U4.4, U5.4, U6.4, U7.4, U8.4, U9.4
/ledArray/R: J1.7, U6.2
/ledArray/ROWblank: J1.16, J2.16, U1.13, U2.13, U3.13
/ledArray/ROWdat: J1.14, U1.14
/ledArray/ROWlatch: J1.15, J2.15, U1.12, U2.12, U3.12
/ledArray/ROWout: J2.14, U3.9
/ledArray/Rout: J2.7, U7.22
/ledArray/SCLK: J1.10, J2.10, U1.11, U2.11, U3.11, U4.3, U5.3, U6.3, U7.3, U8.3, U9.3
/ledArray/sheet5D7D53E6/COM: D193.1, D194.1, D195.1, D196.1, D197.1, D198.1, D199.1, D200.1, D201.1, D202.1, D203.1, D204.1, D205.1, D206.1, D207.1, D208.1, D209.1, D210.1, D211.1, D212.1, D213.1, D214.1, D215.1, D216.1, Q2.3
/ledArray/sheet5D7D53F6/COM: D217.1, D218.1, D219.1, D220.1, D221.1, D222.1, D223.1, D224.1, D225.1, D226.1, D227.1, D228.1, D229.1, D230.1, D231.1, D232.1, D233.1, D234.1, D235.1, D236.1, D237.1, D238.1, D239.1, D240.1, Q5.3
/ledArray/sheet5D7D542A/COM: D289.1, D290.1, D291.1, D292.1, D293.1, D294.1, D295.1, D296.1, D297.1, D298.1, D299.1, D300.1, D301.1, D302.1, D303.1, D304.1, D305.1, D306.1, D307.1, D308.1, D309.1, D310.1, D311.1, D312.1, Q14.3
/ledArray/sheet5D7D543A/COM: D313.1, D314.1, D315.1, D316.1, D317.1, D318.1, D319.1, D320.1, D321.1, D322.1, D323.1, D324.1, D325.1, D326.1, D327.1, D328.1, D329.1, D330.1, D331.1, D332.1, D333.1, D334.1, D335.1, D336.1, Q17.3
/ledArray/sheet5D7D544C/COM: D337.1, D338.1, D339.1, D340.1, D341.1, D342.1, D343.1, D344.1, D345.1, D346.1, D347.1, D348.1, D349.1, D350.1, D351.1, D352.1, D353.1, D354.1, D355.1, D356.1, D357.1, D358.1, D359.1, D360.1, Q20.3
/ledArray/sheet5D7D545C/COM: D361.1, D362.1, D363.1, D364.1, D365.1, D366.1, D367.1, D368.1, D369.1, D370.1, D371.1, D372.1, D373.1, D374.1, D375.1, D376.1, D377.1, D378.1, D379.1, D380.1, D381.1, D382.1, D383.1, D384.1, Q23.3
/ledArray/sheet5D7D5408/COM: D241.1, D242.1, D243.1, D244.1, D245.1, D246.1, D247.1, D248.1, D249.1, D250.1, D251.1, D252.1, D253.1, D254.1, D255.1, D256.1, D257.1, D258.1, D259.1, D260.1, D261.1, D262.1, D263.1, D264.1, Q8.3
/ledArray/sheet5D7D5419/COM: D265.1, D266.1, D267.1, D268.1, D269.1, D270.1, D271.1, D272.1, D273.1, D274.1, D275.1, D276.1, D277.1, D278.1, D279.1, D280.1, D281.1, D282.1, D283.1, D284.1, D285.1, D286.1, D287.1, D288.1, Q11.3
/ledArray/sheet5D82B2A6/COM: D457.1, D458.1, D459.1, D460.1, D461.1, D462.1, D463.1, D464.1, D465.1, D466.1, D467.1, D468.1, D469.1, D470.1, D471.1, D472.1, D473.1, D474.1, D475.1, D476.1, D477.1, D478.1, D479.1, D480.1, Q12.3
/ledArray/sheet5D82B2B7/COM: D481.1, D482.1, D483.1, D484.1, D485.1, D486.1, D487.1, D488.1, D489.1, D490.1, D491.1, D492.1, D493.1, D494.1, D495.1, D496.1, D497.1, D498.1, D499.1, D500.1, D501.1, D502.1, D503.1, D504.1, Q15.3
/ledArray/sheet5D82B2C7/COM: D505.1, D506.1, D507.1, D508.1, D509.1, D510.1, D511.1, D512.1, D513.1, D514.1, D515.1, D516.1, D517.1, D518.1, D519.1, D520.1, D521.1, D522.1, D523.1, D524.1, D525.1, D526.1, D527.1, D528.1, Q18.3
/ledArray/sheet5D82B2D9/COM: D529.1, D530.1, D531.1, D532.1, D533.1, D534.1, D535.1, D536.1, D537.1, D538.1, D539.1, D540.1, D541.1, D542.1, D543.1, D544.1, D545.1, D546.1, D547.1, D548.1, D549.1, D550.1, D551.1, D552.1, Q21.3
/ledArray/sheet5D82B2E9/COM: D553.1, D554.1, D555.1, D556.1, D557.1, D558.1, D559.1, D560.1, D561.1, D562.1, D563.1, D564.1, D565.1, D566.1, D567.1, D568.1, D569.1, D570.1, D571.1, D572.1, D573.1, D574.1, D575.1, D576.1, Q24.3
/ledArray/sheet5D82B273/COM: D385.1, D386.1, D387.1, D388.1, D389.1, D390.1, D391.1, D392.1, D393.1, D394.1, D395.1, D396.1, D397.1, D398.1, D399.1, D400.1, D401.1, D402.1, D403.1, D404.1, D405.1, D406.1, D407.1, D408.1, Q3.3
/ledArray/sheet5D82B283/COM: D409.1, D410.1, D411.1, D412.1, D413.1, D414.1, D415.1, D416.1, D417.1, D418.1, D419.1, D420.1, D421.1, D422.1, D423.1, D424.1, D425.1, D426.1, D427.1, D428.1, D429.1, D430.1, D431.1, D432.1, Q6.3
/ledArray/sheet5D82B295/COM: D433.1, D434.1, D435.1, D436.1, D437.1, D438.1, D439.1, D440.1, D441.1, D442.1, D443.1, D444.1, D445.1, D446.1, D447.1, D448.1, D449.1, D450.1, D451.1, D452.1, D453.1, D454.1, D455.1, D456.1, Q9.3
/ledArray/sheet5D7371BF/COM: D1.1, D2.1, D3.1, D4.1, D5.1, D6.1, D7.1, D8.1, D9.1, D10.1, D11.1, D12.1, D13.1, D14.1, D15.1, D16.1, D17.1, D18.1, D19.1, D20.1, D21.1, D22.1, D23.1, D24.1, Q1.3
/ledArray/sheet5D7371D0/COM: D25.1, D26.1, D27.1, D28.1, D29.1, D30.1, D31.1, D32.1, D33.1, D34.1, D35.1, D36.1, D37.1, D38.1, D39.1, D40.1, D41.1, D42.1, D43.1, D44.1, D45.1, D46.1, D47.1, D48.1, Q4.3
/ledArray/sheet5D7371E3/COM: D49.1, D50.1, D51.1, D52.1, D53.1, D54.1, D55.1, D56.1, D57.1, D58.1, D59.1, D60.1, D61.1, D62.1, D63.1, D64.1, D65.1, D66.1, D67.1, D68.1, D69.1, D70.1, D71.1, D72.1, Q7.3
/ledArray/sheet5D7371F5/COM: D73.1, D74.1, D75.1, D76.1, D77.1, D78.1, D79.1, D80.1, D81.1, D82.1, D83.1, D84.1, D85.1, D86.1, D87.1, D88.1, D89.1, D90.1, D91.1, D92.1, D93.1, D94.1, D95.1, D96.1, Q10.3
/ledArray/sheet5D73722B/COM: D145.1, D146.1, D147.1, D148.1, D149.1, D150.1, D151.1, D152.1, D153.1, D154.1, D155.1, D156.1, D157.1, D158.1, D159.1, D160.1, D161.1, D162.1, D163.1, D164.1, D165.1, D166.1, D167.1, D168.1, Q19.3
/ledArray/sheet5D73723C/COM: D169.1, D170.1, D171.1, D172.1, D173.1, D174.1, D175.1, D176.1, D177.1, D178.1, D179.1, D180.1, D181.1, D182.1, D183.1, D184.1, D185.1, D186.1, D187.1, D188.1, D189.1, D190.1, D191.1, D192.1, Q22.3
/ledArray/sheet5D737207/COM: D97.1, D98.1, D99.1, D100.1, D101.1, D102.1, D103.1, D104.1, D105.1, D106.1, D107.1, D108.1, D109.1, D110.1, D111.1, D112.1, D113.1, D114.1, D115.1, D116.1, D117.1, D118.1, D119.1, D120.1, Q13.3
/ledArray/sheet5D737218/COM: D121.1, D122.1, D123.1, D124.1, D125.1, D126.1, D127.1, D128.1, D129.1, D130.1, D131.1, D132.1, D133.1, D134.1, D135.1, D136.1, D137.1, D138.1, D139.1, D140.1, D141.1, D142.1, D143.1, D144.1, Q16.3
COL_BA0: D1.4, D25.4, D49.4, D73.4, D97.4, D121.4, D145.4, D169.4, D193.4, D217.4, D241.4, D265.4, D289.4, D313.4, D337.4, D361.4, D385.4, D409.4, D433.4, D457.4, D481.4, D505.4, D529.4, D553.4, U8.5
COL_BA1: D2.4, D26.4, D50.4, D74.4, D98.4, D122.4, D146.4, D170.4, D194.4, D218.4, D242.4, D266.4, D290.4, D314.4, D338.4, D362.4, D386.4, D410.4, D434.4, D458.4, D482.4, D506.4, D530.4, D554.4, U8.6
COL_BA2: D3.4, D27.4, D51.4, D75.4, D99.4, D123.4, D147.4, D171.4, D195.4, D219.4, D243.4, D267.4, D291.4, D315.4, D339.4, D363.4, D387.4, D411.4, D435.4, D459.4, D483.4, D507.4, D531.4, D555.4, U8.7
COL_BA3: D4.4, D28.4, D52.4, D76.4, D100.4, D124.4, D148.4, D172.4, D196.4, D220.4, D244.4, D268.4, D292.4, D316.4, D340.4, D364.4, D388.4, D412.4, D436.4, D460.4, D484.4, D508.4, D532.4, D556.4, U8.8
COL_BA4: D5.4, D29.4, D53.4, D77.4, D101.4, D125.4, D149.4, D173.4, D197.4, D221.4, D245.4, D269.4, D293.4, D317.4, D341.4, D365.4, D389.4, D413.4, D437.4, D461.4, D485.4, D509.4, D533.4, D557.4, U8.9
COL_BA5: D6.4, D30.4, D54.4, D78.4, D102.4, D126.4, D150.4, D174.4, D198.4, D222.4, D246.4, D270.4, D294.4, D318.4, D342.4, D366.4, D390.4, D414.4, D438.4, D462.4, D486.4, D510.4, D534.4, D558.4, U8.10
COL_BA6: D7.4, D31.4, D55.4, D79.4, D103.4, D127.4, D151.4, D175.4, D199.4, D223.4, D247.4, D271.4, D295.4, D319.4, D343.4, D367.4, D391.4, D415.4, D439.4, D463.4, D487.4, D511.4, D535.4, D559.4, U8.11
COL_BA7: D8.4, D32.4, D56.4, D80.4, D104.4, D128.4, D152.4, D176.4, D200.4, D224.4, D248.4, D272.4, D296.4, D320.4, D344.4, D368.4, D392.4, D416.4, D440.4, D464.4, D488.4, D512.4, D536.4, D560.4, U8.12
COL_BA8: D9.4, D33.4, D57.4, D81.4, D105.4, D129.4, D153.4, D177.4, D201.4, D225.4, D249.4, D273.4, D297.4, D321.4, D345.4, D369.4, D393.4, D417.4, D441.4, D465.4, D489.4, D513.4, D537.4, D561.4, U8.13
COL_BA9: D10.4, D34.4, D58.4, D82.4, D106.4, D130.4, D154.4, D178.4, D202.4, D226.4, D250.4, D274.4, D298.4, D322.4, D346.4, D370.4, D394.4, D418.4, D442.4, D466.4, D490.4, D514.4, D538.4, D562.4, U8.14
COL_BA10: D11.4, D35.4, D59.4, D83.4, D107.4, D131.4, D155.4, D179.4, D203.4, D227.4, D251.4, D275.4, D299.4, D323.4, D347.4, D371.4, D395.4, D419.4, D443.4, D467.4, D491.4, D515.4, D539.4, D563.4, U8.15
COL_BA11: D12.4, D36.4, D60.4, D84.4, D108.4, D132.4, D156.4, D180.4, D204.4, D228.4, D252.4, D276.4, D300.4, D324.4, D348.4, D372.4, D396.4, D420.4, D444.4, D468.4, D492.4, D516.4, D540.4, D564.4, U8.16
COL_BA12: D13.4, D37.4, D61.4, D85.4, D109.4, D133.4, D157.4, D181.4, D205.4, D229.4, D253.4, D277.4, D301.4, D325.4, D349.4, D373.4, D397.4, D421.4, D445.4, D469.4, D493.4, D517.4, D541.4, D565.4, U8.17
COL_BA13: D14.4, D38.4, D62.4, D86.4, D110.4, D134.4, D158.4, D182.4, D206.4, D230.4, D254.4, D278.4, D302.4, D326.4, D350.4, D374.4, D398.4, D422.4, D446.4, D470.4, D494.4, D518.4, D542.4, D566.4, U8.18
COL_BA14: D15.4, D39.4, D63.4, D87.4, D111.4, D135.4, D159.4, D183.4, D207.4, D231.4, D255.4, D279.4, D303.4, D327.4, D351.4, D375.4, D399.4, D423.4, D447.4, D471.4, D495.4, D519.4, D543.4, D567.4, U8.19
COL_BA15: D16.4, D40.4, D64.4, D88.4, D112.4, D136.4, D160.4, D184.4, D208.4, D232.4, D256.4, D280.4, D304.4, D328.4, D352.4, D376.4, D400.4, D424.4, D448.4, D472.4, D496.4, D520.4, D544.4, D568.4, U8.20
COL_BA16: D17.4, D41.4, D65.4, D89.4, D113.4, D137.4, D161.4, D185.4, D209.4, D233.4, D257.4, D281.4, D305.4, D329.4, D353.4, D377.4, D401.4, D425.4, D449.4, D473.4, D497.4, D521.4, D545.4, D569.4, U9.5
COL_BA17: D18.4, D42.4, D66.4, D90.4, D114.4, D138.4, D162.4, D186.4, D210.4, D234.4, D258.4, D282.4, D306.4, D330.4, D354.4, D378.4, D402.4, D426.4, D450.4, D474.4, D498.4, D522.4, D546.4, D570.4, U9.6
COL_BA18: D19.4, D43.4, D67.4, D91.4, D115.4, D139.4, D163.4, D187.4, D211.4, D235.4, D259.4, D283.4, D307.4, D331.4, D355.4, D379.4, D403.4, D427.4, D451.4, D475.4, D499.4, D523.4, D547.4, D571.4, U9.7
COL_BA19: D20.4, D44.4, D68.4, D92.4, D116.4, D140.4, D164.4, D188.4, D212.4, D236.4, D260.4, D284.4, D308.4, D332.4, D356.4, D380.4, D404.4, D428.4, D452.4, D476.4, D500.4, D524.4, D548.4, D572.4, U9.8
COL_BA20: D21.4, D45.4, D69.4, D93.4, D117.4, D141.4, D165.4, D189.4, D213.4, D237.4, D261.4, D285.4, D309.4, D333.4, D357.4, D381.4, D405.4, D429.4, D453.4, D477.4, D501.4, D525.4, D549.4, D573.4, U9.9
COL_BA21: D22.4, D46.4, D70.4, D94.4, D118.4, D142.4, D166.4, D190.4, D214.4, D238.4, D262.4, D286.4, D310.4, D334.4, D358.4, D382.4, D406.4, D430.4, D454.4, D478.4, D502.4, D526.4, D550.4, D574.4, U9.10
COL_BA22: D23.4, D47.4, D71.4, D95.4, D119.4, D143.4, D167.4, D191.4, D215.4, D239.4, D263.4, D287.4, D311.4, D335.4, D359.4, D383.4, D407.4, D431.4, D455.4, D479.4, D503.4, D527.4, D551.4, D575.4, U9.11
COL_BA23: D24.4, D48.4, D72.4, D96.4, D120.4, D144.4, D168.4, D192.4, D216.4, D240.4, D264.4, D288.4, D312.4, D336.4, D360.4, D384.4, D408.4, D432.4, D456.4, D480.4, D504.4, D528.4, D552.4, D576.4, U9.12
COL_GA0: D1.3, D25.3, D49.3, D73.3, D97.3, D121.3, D145.3, D169.3, D193.3, D217.3, D241.3, D265.3, D289.3, D313.3, D337.3, D361.3, D385.3, D409.3, D433.3, D457.3, D481.3, D505.3, D529.3, D553.3, U4.5
COL_GA1: D2.3, D26.3, D50.3, D74.3, D98.3, D122.3, D146.3, D170.3, D194.3, D218.3, D242.3, D266.3, D290.3, D314.3, D338.3, D362.3, D386.3, D410.3, D434.3, D458.3, D482.3, D506.3, D530.3, D554.3, U4.6
COL_GA2: D3.3, D27.3, D51.3, D75.3, D99.3, D123.3, D147.3, D171.3, D195.3, D219.3, D243.3, D267.3, D291.3, D315.3, D339.3, D363.3, D387.3, D411.3, D435.3, D459.3, D483.3, D507.3, D531.3, D555.3, U4.7
COL_GA3: D4.3, D28.3, D52.3, D76.3, D100.3, D124.3, D148.3, D172.3, D196.3, D220.3, D244.3, D268.3, D292.3, D316.3, D340.3, D364.3, D388.3, D412.3, D436.3, D460.3, D484.3, D508.3, D532.3, D556.3, U4.8
COL_GA4: D5.3, D29.3, D53.3, D77.3, D101.3, D125.3, D149.3, D173.3, D197.3, D221.3, D245.3, D269.3, D293.3, D317.3, D341.3, D365.3, D389.3, D413.3, D437.3, D461.3, D485.3, D509.3, D533.3, D557.3, U4.9
COL_GA5: D6.3, D30.3, D54.3, D78.3, D102.3, D126.3, D150.3, D174.3, D198.3, D222.3, D246.3, D270.3, D294.3, D318.3, D342.3, D366.3, D390.3, D414.3, D438.3, D462.3, D486.3, D510.3, D534.3, D558.3, U4.10
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

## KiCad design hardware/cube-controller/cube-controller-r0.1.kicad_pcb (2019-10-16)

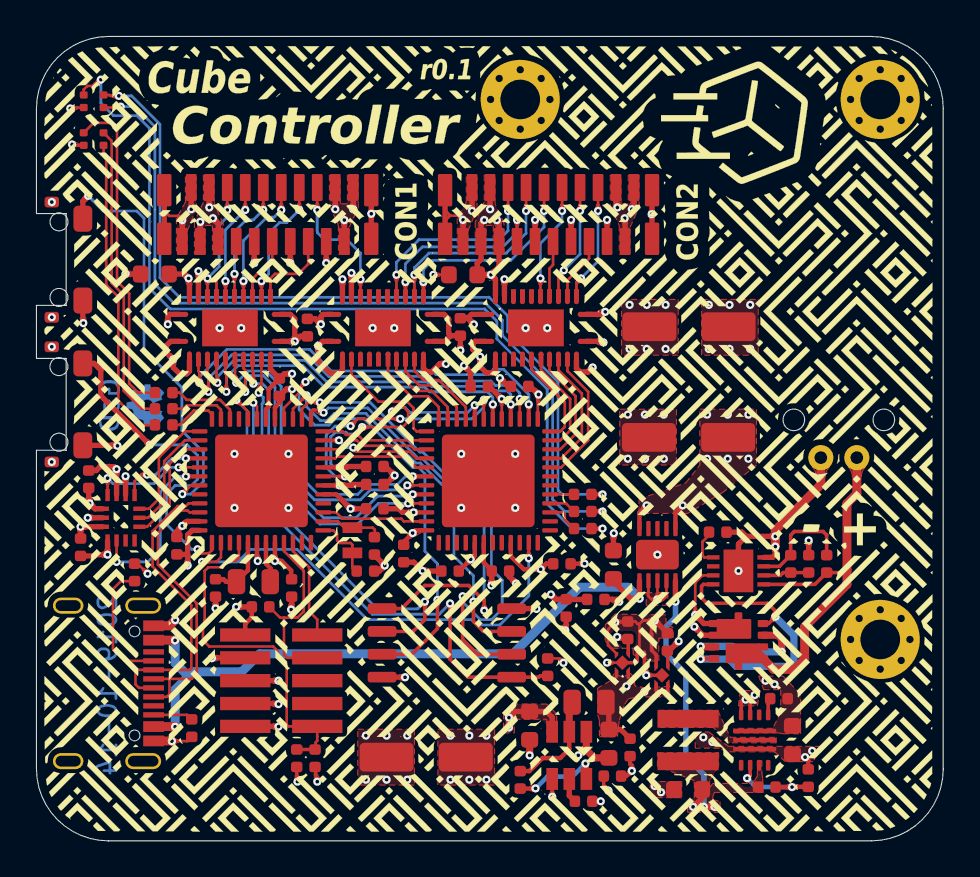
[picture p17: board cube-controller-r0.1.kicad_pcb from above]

Board: 4 copper layers, 50.4 x 44.7 mm, 83 parts (0 on the bottom side), 103 nets.

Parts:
C1, C2, C4, C5, C26, C28, C33: 10uF; C_0603_1608Metric
C3, C12, C13, C14, C15, C19, C20, C21, C22, C23, C24, C25, C27, C29, C30, C31, C32: 100nF; C_0402_1005Metric
C6, C7, C8, C16: 1uF; C_0402_1005Metric
C9, C10, C11: CP1; CP_Elec_5x3.9
C17, C18: 22pF; C_0402_1005Metric
D1, D2: LED_ARGB; led_rbag_1515
FB1: Ferrite_Bead_Small; L_0402_1005Metric
J1: Conn_01x02; SB02B-PASK-2
J2, J3: Conn_01x20_Shielded; FH12-20S-0.5SVA(54)
J4: Conn_02x05_Odd_Even; FTSH-105-XX-X-DV
J5: USB_C_Receptacle_USB2.0; USB_C_Receptacle_Palconn_UTC16-G
L1: 1uH; L_Coilcraft_XxL4020
L2: 2.2uH; L_0805_2012Metric
L3: 10uH; L_0805_2012Metric
R1: 510k; R_0402_1005Metric
R2, R3: 150k; R_0402_1005Metric
R4: 5.1M; R_0402_1005Metric
R5, R8: 100k; R_0402_1005Metric
R6, R7, R9, R10: R; R_0402_1005Metric
R11, R12, R13, R14, R15, R16: 470R; R_0402_1005Metric
R17, R19, R20: 10k; R_0402_1005Metric
R18: 1k; R_0402_1005Metric
R21, R22: 5.1k; R_0402_1005Metric
SW1, SW2: SW_Push; EVQP4
U1: LTC4367; DFN-8-1EP_3x3mm_P0.5mm_EP1.66x2.38mm
U2: AON7804; DFN3X3_8L_EP2_P
U3: TPS62135; VQFN-11_3x2mm_P0.5mm
U4: TPS561201; TSOT-23-6
U5: NP115-2.5; X2SON_4_1.0x1.0mm
U6: NP115-1.2; X2SON_4_1.0x1.0mm
U7: ATSAMD51G19A; QFN-48-1EP_7x7mm_P0.5mm_EP5.15x5.15mm
U8: ICE40UP5K-SG48ITR; QFN-48-1EP_7x7mm_P0.5mm_EP5.15x5.15mm
U9, U10, U11: SN74AVC8T245PW; Texas_RGY_R-PVQFN-N24_EP2.05x3.1mm
U12: BMX160; Bosch_LGA-14_3x2.5mm_P0.5mm
U13: AT25SF081; SOIC-8_5.23x5.23mm_P1.27mm
U14: LTC4413-2; DFN-10-1EP_3x3mm_P0.5mm_EP1.65x2.38mm
Y1: 32.768kHz; Crystal_SMD_2012-2Pin_2.0x1.2mm

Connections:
1v2: C7.1, C24.1, C25.1, FB1.1, U6.1, U8.5, U8.30
1v2_pll: C8.1, C23.1, FB1.2, U8.29
2v5: C6.1, C22.1, U5.1, U8.24
3v3: C5.1, C12.1, C13.1, C14.1, C15.1, C19.1, C20.1, C21.1, C31.1, C32.1, D1.1, D2.1, J4.1, L2.2, R9.2, R18.2, R19.2, R20.2, U5.3, U5.4, U6.3, U6.4, U7.6, U7.17, U7.36, U7.44, U8.1, U8.22, U8.33, U9.1, U9.2, U10.1, U10.2, U11.1, U11.2, U12.5, U12.8, U13.8
3v3_fb: R9.1, R10.1, U4.4
4v5: C4.1, C9.1, C10.1, C11.1, C26.1, C27.1, C28.1, C29.1, J2.3, J2.4, J2.5, J2.18, J2.19, J2.20, J3.3, J3.4, J3.5, J3.18, J3.19, J3.20, R8.2, U4.3, U9.23, U9.24, U10.23, U10.24, U11.23, U11.24, U14.6, U14.10
4v5_in: C2.1, L1.2, R6.2, U3.6, U14.5
5v0_usb: C33.1, J5.A4, J5.A9, J5.B4, J5.B9, U14.1
5v_fb: R6.1, R7.1, U3.5
unnamed: U2.2, U2.5
unnamed: U1.8, U2.3, U2.6
unnamed: R1.1, U1.5
unnamed: R2.2, R3.1, U1.3
unnamed: R3.2, R4.1, U1.2
unnamed: R5.1, U3.8
unnamed: L1.1, U3.2
unnamed: R8.1, U4.5
unnamed: C3.1, U4.6
unnamed: C3.2, L2.1, U4.2
unnamed: C16.1, L3.2, U7.41
unnamed: R11.1, U7.22
unnamed: R12.1, U7.24
unnamed: R13.1, U7.23
unnamed: C18.1, U7.2, Y1.2
unnamed: C17.1, U7.1, Y1.1
unnamed: R14.1, U8.39
unnamed: R15.1, U8.40
unnamed: R16.1, U8.41
unnamed: U7.38, U8.35
unnamed: U7.3, U8.23
unnamed: SW1.1, U7.37
unnamed: SW2.1, U7.31
unnamed: L3.1, U7.43
cc1: J5.A5, R21.1
cc2: J5.B5, R22.1
gnd: C1.2, C2.2, C4.2, C5.2, C6.2, C7.2, C8.2, C9.2, C10.2, C11.2, C12.2, C13.2, C14.2, C15.2, C16.2, C17.2, C18.2, C19.2, C20.2, C21.2, C22.2, C23.2, C24.2, C25.2, C26.2, C27.2, C28.2, C29.2, C30.2, C31.2, C32.2, C33.2, J1.2, J2.1, J2.2, J2.9, J2.13, J2.17, J2.SH, J3.1, J3.2, J3.9, J3.13, J3.17, J3.SH, J4.3, J4.5, J4.7, J4.9, J5.A1, J5.A12, J5.B1, J5.B12, J5.S1, R1.2, R4.2, R7.2, R10.2, R17.2, R21.2, R22.2, SW1.2, SW2.2, U1.4, U3.3, U3.10, U3.11, U4.1, U5.2, U6.2, U7.5, U7.18, U7.35, U7.42, U7.49, U8.49, U9.11, U9.12, U9.13, U9.22, U10.11, U10.12, U10.13, U10.22, U11.11, U11.12, U11.13, U11.22, U12.2, U12.3, U12.6, U12.7, U13.4, U14.2, U14.3, U14.4, U14.11
ice_config_done: U7.7, U8.7
ice_config_miso: U7.12, U8.14
ice_config_mosi: U7.9, U8.17
ice_config_reset: R17.1, U7.8, U8.8
ice_config_sck: U7.10, U8.15
ice_config_ss: U7.11, U8.16
ice_led_b: D2.4, R16.2
ice_led_g: D2.3, R15.2
ice_led_r: D2.2, R14.2
imu_cs: U7.27, U12.12
imu_int1: U7.29, U12.4
imu_int2: U7.30, U12.9
imu_miso: U7.28, U12.1
imu_mosi: U7.25, U12.14
imu_sck: U7.26, U12.13
led_b: D1.4, R13.2
led_g: D1.3, R12.2
led_r: D1.2, R11.2
pb0_b_blank: J2.12, U9.17
pb0_b_db: J2.8, U9.19
pb0_b_dg: J2.7, U9.20
pb0_b_dr: J2.6, U9.21
pb0_b_latch: J2.11, U9.16
pb0_b_rblank: J2.16, U10.21
pb0_b_rdata: J2.14, U9.15
pb0_b_rlatch: J2.15, U9.14
pb0_b_sclk: J2.10, U9.18
pb0_blank: U8.18, U9.7
pb0_db: U8.4, U9.5
pb0_dg: U8.3, U9.4
pb0_dr: U8.2, U9.3
pb0_latch: U8.19, U9.8
pb0_rblank: U8.13, U10.3
pb0_rdata: U8.20, U9.9
pb0_rlatch: U8.21, U9.10
pb0_sclk: U8.6, U9.6
pb1_b_blank: J3.12, U11.18
pb1_b_db: J3.8, U10.15
pb1_b_dg: J3.7, U10.16
pb1_b_dr: J3.6, U10.17
pb1_b_latch: J3.11, U11.17
pb1_b_rblank: J3.16, U11.14
pb1_b_rdata: J3.14, U11.16
pb1_b_rlatch: J3.15, U11.15
pb1_b_sclk: J3.10, U10.14
pb1_blank: U8.48, U11.6
pb1_db: U8.10, U10.9
pb1_dg: U8.11, U10.8
pb1_dr: U8.12, U10.7
pb1_latch: U8.47, U11.7
pb1_rblank: U8.44, U11.10
pb1_rdata: U8.46, U11.8
pb1_rlatch: U8.45, U11.9
pb1_sclk: U8.9, U10.10
pp_batt: J1.1, R2.1, U1.1, U2.4
pp_batt_prot: C1.1, R5.2, U1.7, U2.1, U3.1
qspi_bus_cs: R20.1, U7.20, U13.1
qspi_bus_io0: U7.13, U13.5
qspi_bus_io1: U7.14, U13.2
qspi_bus_io2: U7.15, U13.3
qspi_bus_io3: U7.16, U13.7
qspi_bus_sck: U7.19, U13.6
samd_rst: C30.1, J4.10, R19.1, U7.40
samd_usb_n: J5.A7, J5.B7, U7.33
samd_usb_p: J5.A6, J5.B6, U7.34
swdclk: J4.4, R18.1, U7.45
swdio: J4.2, U7.46

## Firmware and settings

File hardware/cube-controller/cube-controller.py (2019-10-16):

# -*- coding: utf-8 -*-

from skidl import *
from string import ascii_uppercase
import subprocess


def place_part_inline(pin_net, part):
    out_net = Net()
    part[1] += out_net
    part[2] += pin_net
    return out_net

def add_decopling(nets, part):
    for n in nets:
        p = part()
        p[1] += n
        p[2] += Net.get('gnd')

class CubeController():


    def __init__(self):

        #===============================================================================
        # Component templates.
        #===============================================================================

        output_connector = Part('Connector_Generic_Shielded', 'Conn_01x20_Shielded', dest=TEMPLATE, footprint='gkl_conn:FH12-20S-0.5SVA(54)', PN='FH12-20S-0.5SVA(54)', Manf='Hirose Electric Co Ltd')
        d_74lvc8t245 = Part('Logic_LevelTranslator', 'SN74AVC8T245PW', dest=TEMPLATE, footprint='Package_DFN_QFN:Texas_RGY_R-PVQFN-N24_EP2.05x3.1mm', PN='SN74AVC8T245RHLR', Manf='Texas Instruments')
        
        samd51 = Part('gkl_microchip', 'ATSAMD51G19A', dest=TEMPLATE, footprint='Package_DFN_QFN:QFN-48-1EP_7x7mm_P0.5mm_EP5.15x5.15mm', PN='ATSAMD51G19A-MF', Manf='Microchip Technology')
        c_100uF = Part('Device', 'CP1', dest=TEMPLATE, footprint='Capacitor_SMD:CP_Elec_5x3.9', PN='UWX1C101MCL1GB', Manf='Nichicon')
        c_100nF = Part('Device', 'C', dest=TEMPLATE, footprint='Capacitor_SMD:C_0402_1005Metric', value='100nF', PN='CL05B104KP5NNNC', Manf='Samsung Electro-Mechanics')
        cap = Part('Device', 'C', dest=TEMPLATE, footprint='Capacitor_SMD:C_0402_1005Metric')
        rgb = Part('Device', 'LED_ARGB', dest=TEMPLATE, footprint='gkl_led:led_rbag_1515', PN='MHPA1515RGBDT', Manf='Meihua')
        res = Part('Device', 'R', dest=TEMPLATE, footprint='Resistor_SMD:R_0402_1005Metric')

        ice40up5k = Part('FPGA_Lattice', 'ICE40UP5K-SG48ITR', dest=TEMPLATE, footprint='Package_DFN_QFN:QFN-48-1EP_7x7mm_P0.5mm_EP5.15x5.15mm', PN='ICE40UP5K-SG48I', Manf='Lattice Semiconductor Corporation')
    
        d_tps62135 = Part('gkl_misc', 'TPS62135', dest=TEMPLATE, footprint='gkl_misc:VQFN-11_3x2mm_P0.5mm', PN='TPS621351RGXR', Manf='Texas Instruments')
        d_cap_10uf_16V_0603 = Part('Device', 'C', dest=TEMPLATE, footprint='Capacitor_SMD:C_0603_1608Metric', value='10uF', PN='GRM188R61C106MAALD', Manf='Murata Electronics')
        d_cap_1uf_6_3V_0402 = Part('Device', 'C', dest=TEMPLATE, footprint='Capacitor_SMD:C_0402_1005Metric', value='1uF', PN='CL05A105MQ5NNNC', Manf='Samsung Electro-Mechanics')
        d_inductor_1uH = Part('Device', 'L', dest=TEMPLATE, footprint='Inductor_SMD:L_Coilcraft_XxL4020', value='1uH', PN='78438357010', Manf='Wurth Electronics Inc.')
        d_inductor_2_2uH = Part('Device', 'L', dest=TEMPLATE, footprint='Inductor_SMD:L_0805_2012Metric', value='2.2uH', PN='LQM21FN2R2N00D', Manf='Murata Electronics')
        d_inductor_10uH = Part('Device', 'L', dest=TEMPLATE, footprint='Inductor_SMD:L_0805_2012Metric', value='10uH', PN='LQM21FN100M70L', Manf='Murata Electronics')

        d_tps561201 = Part('gkl_pmic', 'TPS561201', dest=TEMPLATE, footprint='Package_TO_SOT_SMD:TSOT-23-6', PN='TPS561201DDCT', Manf='Texas Instruments')
        

        d_con_10P_2x5 = Part('Connector_Generic', 'Conn_02x05_Odd_Even', dest=TEMPLATE, footprint='gkl_conn:FTSH-105-XX-X-DV', PN='FTSH-105-01-F-DV-K-TR', Manf='Samtec Inc.')
        d_qspi_flash = Part('gkl_mem', 'AT25SF081', dest=TEMPLATE, footprint='Package_SO:SOIC-8_5.23x5.23mm_P1.27mm', PN='W25Q128JVSIM TR', Manf='Winbond Electronics')

        d_button = Part('Switch', 'SW_Push', dest=TEMPLATE, footprint='gkl_misc:EVQP4', PN='EVQ-P42B3M', Manf='Panasonic Electronic Components')

        d_usb = Part('Connector', 'USB_C_Receptacle_USB2.0', dest=TEMPLATE, footprint='Connector_USB:USB_C_Receptacle_Palconn_UTC16-G', PN='CX90M-16P', Manf='Hirose Electric Co Ltd')

        d_bmx160 = Part('gkl_misc', 'BMX160', dest=TEMPLATE, footprint='Package_LGA:Bosch_LGA-14_3x2.5mm_P0.5mm', PN='BMX160', Manf='Bosch Sensortec')

        d_crystal = Part('Device', 'Crystal', dest=TEMPLATE, footprint='Crystal:Crystal_SMD_2012-2Pin_2.0x1.2mm', PN='ECS-.327-9-12R-C-TR', Manf='ECS Inc.')
        d_con_JST_PA_2 = Part('Connector_Generic', 'Conn_01x02', dest=TEMPLATE, footprint='gkl_conn:SB02B-PASK-2', PN='S02B-PASK-2(LF)(SN)', Manf='JST Sales America Inc.')

        d_ltc4367 = Part('gkl_pmic', 'LTC4367', dest=TEMPLATE, footprint='Package_DFN_QFN:DFN-8-1EP_3x3mm_P0.5mm_EP1.66x2.38mm', PN='LTC4367IDD#PBF', Manf='Linear Technology/Analog Devices')
        d_aon7804 = Part('gkl_mosfet', 'AON7804', dest=TEMPLATE, footprint='gkl_housings_dfn:DFN3X3_8L_EP2_P', PN='AON7804', Manf='Alpha / Omega Semiconductor Inc.')
        
        d_fb = Part('Device', 'Ferrite_Bead_Small', dest=TEMPLATE, footprint='Inductor_SMD:L_0402_1005Metric', PN='BK1005HS102-T', Manf='Taiyo Yuden')
        d_ncp115 = Part('gkl_pmic', 'NCP167', dest=TEMPLATE, footprint='gkl_housings_son:X2SON_4_1.0x1.0mm')

        d_ltc4413_1 = Part('gkl_pmic', 'LTC4413-2', dest=TEMPLATE, footprint='Package_DFN_QFN:DFN-10-1EP_3x3mm_P0.5mm_EP1.65x2.38mm', PN='LTC4413EDD-1#PBF', Manf='Linear Technology/Analog Devices')
        

        # Battery and protection circuit 


        pp_usb = Net('5v0_usb')
        pp4v5 = Net('4v5')
        pp4v5_in = Net('4v5_in')
        pp3v3 = Net('3v3')
        pp2v5 = Net('2v5')
        pp1v2 = Net('1v2')
        pp1v2_pll = Net('1v2_pll')

        ppbatt_prot = Net('pp_batt_prot')
        ppbatt = Net('pp_batt')


        gnd = Net('gnd')
        self.pp3v3 = pp3v3
        self.gnd = gnd

        
        #===============================================================================
        # Component instantiations.
        #===============================================================================

        ## Power supplies
        
        # Battery Input
        batt_connector = d_con_JST_PA_2()
        batt_connector['1'] += ppbatt
        batt_connector['2'] += gnd

        # Voltage protection/cutoff
        ltc4367 = d_ltc4367()
        aon7804 = d_aon7804()

        # Connect MOSFOTS back to back
        aon7804[2] += aon7804[5]
        aon7804[4] += ppbatt
        aon7804[1] += ppbatt_prot
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

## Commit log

2019-09-07 Updated README, added images of project
    [GlassUnicorn_Cube_r0.1.f3d, GlassUnicorn_Cube_r0.1.iges]
2019-09-07 Added Panel_r0.1 KiCad files, and scripts
    [colDrivers.sch, ledArray.sch, ledStripe.sch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]
2019-09-07 Added first pass at routing a 32x32 panel.
    [colDrivers.sch, ledArray.sch, ledStripe.sch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]
2019-09-07 Updated 32x32_1515 panel.
    [panel_32x32_1515_r0.1.sch, panel_r0.1.sch]
2019-10-13 Added initial version of Cube controller
    [cube-controller-r0.1.kicad_pcb]
2019-10-13 Fix pin1 on SWD connector
    [cube-controller-r0.1.kicad_pcb]
2019-10-16 Updated SKiDL to include orderable part numbers. Exported iBOM for r0.1 CubeController Added Gerbers for CubeController r0.1
    [cube-controller-r0.1.kicad_pcb]
2019-10-16 Add code to invoke KiCad csv BOM. Generate KiCad csv BOM
    [cube-controller.csv]
2021-12-07 Add 3d-printed unibody cube frame
    [GlassUnicorn_Cube_Unibody_r0.2.prt, GlassUnicorn_Cube_Unibody_r0.2.stl]
